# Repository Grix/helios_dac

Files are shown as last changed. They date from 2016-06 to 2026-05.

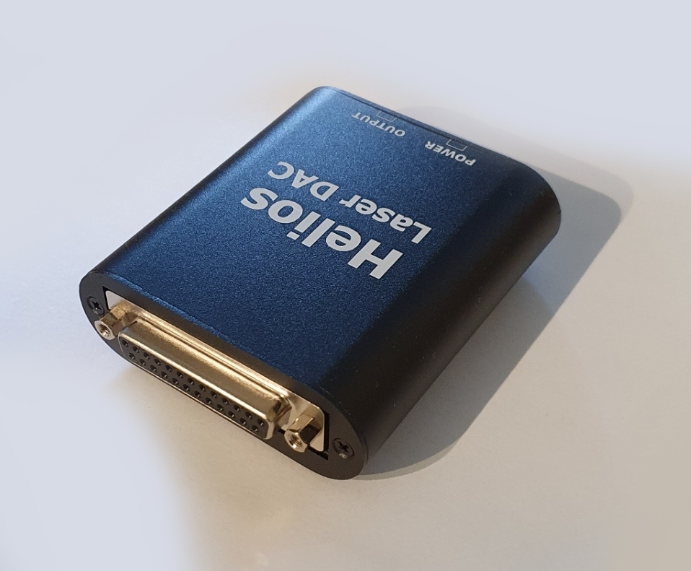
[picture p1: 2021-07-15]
media/helios_ildaside.jpg

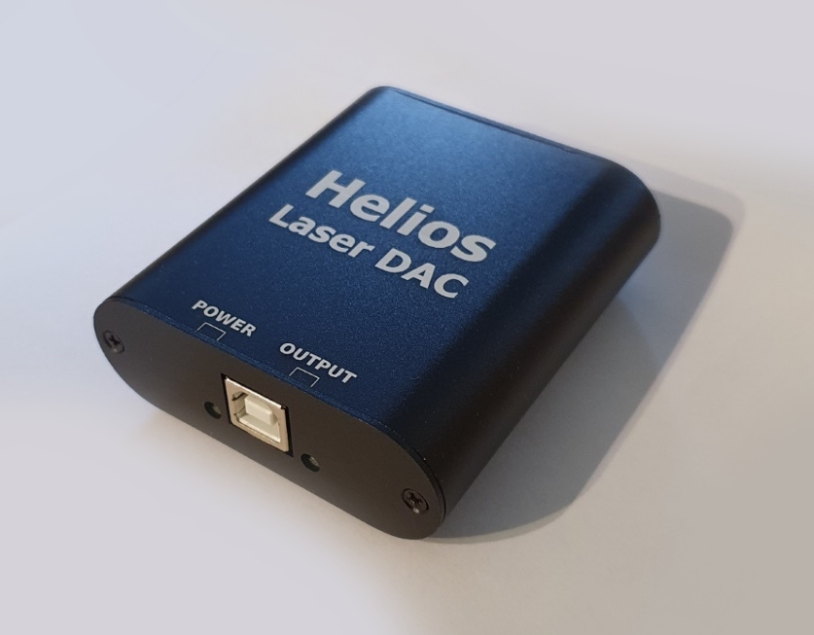
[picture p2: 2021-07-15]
media/helios_usbside.jpg

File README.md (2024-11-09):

# Helios Laser DAC
Digital to Analog Converter for laser projectors.

* https://bitlasers.com/helios-laser-dac/

Open source, low cost USB DAC for the ISP-DB25 (ILDA) laser protocol. Allows you to control an ILDA laser projector via computer over USB. Supports lots of third party software (see link above). This repository consists of:
* SDK for supporting the Helios USB and IDN DACs in your software (with examples in C++, Python and C#/.NET)
* Hardware (PCB schematic in KiCAD)
* Firmware (Atmel Studio project)
* Extras (firmware update tool, media etc.)

## Developer guide

#### Third party software integration

Navigate to the folder "sdk" to find the relevant code for interfacing with the Helios DAC in your software, and a readme with more detailed usage instructions. 

NEW: The C++ sdk has been updated to include IDN network support. This means that if you implement/update the Helios library in your application, it will also seamlessly enable support for any other network DAC using the IDN protocol, including the Helios OpenIDN adapter, StageMate ISP, and upcoming Helios products.
**Other libraries than the C++ one has not yet been updated with IDN support.**

The reference SDK is written in C++, in the subfolder "cpp". But libraries with exported functions that you can call from many languages such as python or C# are available, documented in HeliosDacAPI.h. You can also find examples of usage in the examples folder.

The C++ code depends on libusb. You can use the included libusb binary libraries for Win32, Mac or Linux, or you can build your own. You can find the libusb source on libusb.info, or binaries on https://sourceforge.net/projects/libusb/files/libusb-1.0/

If you wish to use the shared library, there are ready-made builds for Win32 (.dll) and 64-bit linux (.so) in the sdk folder. NB: Only the Windows binary is guaranteed to be up to date. For Mac and Linux it is recommended to build your own or use the C++ classes.

New: There is a native .NET library with example code in sdk/dotnet. HOWEVER, the C# library is not yet updated with IDN (network) support, so it is not recommended for general use yet.

If you are adding support for the Helios in your program, let me know and I can link it on the Helios' website.

Steps to compiling shared library (.so) for Linux based systems yourself is below. For macOS, try replacing ".so" with ".dylib". For Windows, there is a Visual Studio project in the source directory.

```shell
g++ -Wall -std=c++14 -fPIC -O2 -c HeliosDacAPI.cpp
g++ -Wall -std=c++14 -fPIC -O2 -c HeliosDac.cpp
g++ -shared -o libHeliosDacAPI.so HeliosDacAPI.o HeliosDac.o libusb-1.0.so
```
To use the device on Linux you either need root privileges or need to set up udev rules (see https://bitlasers.com/helios-laser-dac/). On Windows and Mac it should be plug and play.

A more detailed guide for compiling for Raspberry Pi (Linux ARM) is also available in the docs folder.

#### Hardware and firmware modification

The PCB is drawn in Kicad. The firmware is written and built with Atmel Studio for the ATSAM4S2B microcontroller.
**NB: The license for the hardware and firmware, unlike the software, does not permit the sale of manufactured units.**
New firmware can be uploaded to the device over USB. To do this, you must reset the "GPNVM1" bit in the flash memory, which will make the microcontroller boot to the SAM-BA bootloader. You can do this by sending a special interrupt packet to the DAC. You can then access the flash using Atmel's SAM-BA software or BOSSA. There is an automatic tool for firmware updating:

* Download the firmware updating tool (only for Windows as of now, Mac/Linux partially done): utility/FirmwareUpdater/cli/firmwareupdater_script.zip
* Unzip, plug in the DAC and run the file "flash.bat".
* Follow the instructions on the screen (you may need to unplug and replug the device a couple of times as instructed).

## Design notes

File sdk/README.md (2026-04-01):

There are currently official libraries for C++ and C#, see the respective subfolders. 
There also exists Rust and Javascript libraries from third parties, but they are not covered here.

**NEW**: As of October 2024, the C++ SDK has been updated to include IDN (network) support. This means that if you implement/update the Helios library in your application, it will also seamlessly enable support for any other network DAC using the IDN protocol, including the Helios OpenIDN adapter, StageMate ISP, and upcoming Helios products. This also enables more capabilities such as higher resolution and more data channels. This is reflected by the choice of multiple WriteFrame\*() functions, such as WriteFrameHighResolution() and WriteFrameExtended(). 
**Since only the C++ library supports this as of now, it is recommended to use that. Other languages can link to the C++ share libraries dynamically.**
The original WriteFrame() with 12-bit XY resolution and 8-bit RGBI channels have been preserved for backwards compatibility and a light-weight alternative, but for new or updated applications, it is recommended to choose at least WriteFrameHighResolution() instead. It gives you the most common channels, XY+RGB, with 16-bit resolution each. It is safe to call this function even if the DAC in use does not support these resolutions, the library will automatically convert the data.

Common to all languages:

BASIC USAGE, common to all languages:
1.	Call OpenDevices() to scan and open devices, returns number of available devices.
2.	To send a new frame, first call GetStatus(). The status should be polled until it returns ready. It can fail to return ready on the first try.
3.  When GetStatus() has returned ready (1), then you can call one of the WriteFrame\*() functions with image data, to output a frame.
4.  Repeat steps 2-3 continuously while you have data to output. If you output to multiple DACs at once, each should have their own thread.
5.  To stop output, use Stop(). To restart output you must send a new frame as described above.
6.	When the DAC(s) are no longer needed, free the connections using CloseDevices().

The DAC is double-buffered. When it receives its first frame, it starts outputting it. When a second frame is sent to 
the DAC while the first frame is being played, the second frame is stored in the DACs memory until the first frame 
finishes playback, at which point the second, buffered frame will start playing. If the DAC finished playback of a frame
without having received and buffered a second frame, it will by default loop the first frame until a new frame is
received (but the flag HELIOS_FLAG_SINGLE_MODE will make it stop playback instead).
The GetStatus() function actually checks whether or not the buffer on the DAC is empty or full. If it is full, the DAC
cannot receive a new frame until the currently playing frame finishes, freeing up the buffer.

----

Did you know that the Helios DAC SDK won first place in the 2025 [ILDA Fenning Award for Technical Achievement (IDN Standards category)](https://www.ilda.com/awards.htm)?

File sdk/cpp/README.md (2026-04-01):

SDK for Helios Laser DAC class  
By Gitle Mikkelsen  
gitlem@gmail.com  

Dependencies:  
Libusb 1.0 (GNU Lesser General Public License, see libusb.h)

Standard: C++14

git repo: https://github.com/Grix/helios_dac.git

BASIC USAGE:
1.	Call OpenDevices() to scan and open devices, returns number of available devices.
2.	To send a new frame, first call GetStatus(). The status should be polled until it returns ready. It can fail to return ready on the first try.
3.  When GetStatus() has returned ready (1), then you can call one of the WriteFrame\*() functions with image data, to output a frame.
4.  Repeat steps 2-3 continuously while you have data to output. If you output to multiple DACs at once, each should have their own thread.
5.  To stop output, use Stop(). To restart output you must send a new frame as described above.
6.	When the DAC(s) are no longer needed, free the connections using CloseDevices().

The DAC is double-buffered. When it receives its first frame, it starts outputting it. When a second frame is sent to 
the DAC while the first frame is being played, the second frame is stored in the DACs memory until the first frame 
finishes playback, at which point the second, buffered frame will start playing. If the DAC finished playback of a frame
without having received and buffered a second frame, it will by default loop the first frame until a new frame is
received (but the flag HELIOS_FLAG_SINGLE_MODE will make it stop playback instead).
The GetStatus() function actually checks whether or not the buffer on the DAC is empty or full. If it is full, the DAC
cannot receive a new frame until the currently playing frame finishes, freeing up the buffer.

**NEW**: As of October 2024, the C++ SDK has been updated to include IDN (network) support. This means that if you implement/update the Helios library in your application, it will also seamlessly enable support for any other network DAC using the IDN protocol, including the Helios OpenIDN adapter, StageMate ISP, and upcoming Helios products. This also enables more capabilities such as higher resolution and more data channels. This is reflected by the choice of multiple WriteFrame\*() functions, such as WriteFrameHighResolution() and WriteFrameExtended(). 
The original WriteFrame() with 12-bit XY resolution and 8-bit RGBI channels have been preserved for backwards compatibility and a light-weight alternative, but for new or updated applications, it is recommended to choose at least WriteFrameHighResolution() instead. It gives you the most common channels, XY+RGB, with 16-bit resolution each. It is safe to call this function even if the DAC in use does not support these resolutions, the library will automatically convert the data.

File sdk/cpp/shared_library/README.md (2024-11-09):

This is the shared library extension of the Helios DAC SDK, used to produce a library file for dynamic linking, like .dll, .so or .dylib. It has compatibility functions with the EzAudDac functions. 
If dynamic linking is not neccessary, you can simply use the files in the parent folder (HeliosDAC.cpp, HeliosDAC.h and the source files in the idn folder) directly in your source code, with no additional files or build steps needed.

NB: These libraries depend on libusb. In addition to HeliosLaserDAC.dll/dylib/so you also need libusb-1.0.dll/dylib/so in the same folder, or installed on the computer some other way. You can find these files in the ../libusb_bin folder.

BASIC USAGE:
1.	Call OpenDevices()  to open devices, returns number of available devices.
2.	To send a new frame, first call GetStatus(). If the function returns ready, (1), then you can call WriteFrame\*().
	The status should be polled until it returns ready. It can and sometimes will fail to return ready on the first try.
3.  To stop output, use Stop(). To restart output you must send a new frame as described above.
4.	When the DAC is no longer needed, free it using CloseDevices().

When the DAC receives its first frame, it starts outputting it. When a second frame is sent to
the DAC while the first frame is being played, the second frame is stored in the DACs memory until the first frame
finishes playback, at which point the second, buffered frame will start playing. If the DAC finished playback of a frame
without having received and buffered a second frame, it will by default loop the first frame until a new frame is
received (but the flag HELIOS_FLAG_SINGLE_MODE will make it stop playback instead).
The GetStatus() function actually checks whether or not the buffer on the DAC is empty or full. If it is full, the DAC
cannot receive a new frame until the currently playing frame finishes, freeing up the buffer.

**NEW**: As of October 2024, the C++ SDK has been updated to include IDN (network) support. This means that if you implement/update the Helios library in your application, it will also seamlessly enable support for any other network DAC using the IDN protocol, including the Helios OpenIDN adapter, StageMate ISP, and upcoming Helios products. This also enables more capabilities such as higher resolution and more data channels. This is reflected by the choice of multiple WriteFrame\*() functions, such as WriteFrameHighResolution() and WriteFrameExtended(). 
The original WriteFrame() with 12-bit XY resolution and 8-bit RGBI channels have been preserved for backwards compatibility and a light-weight alternative, but for new or updated applications, it is recommended to choose at least WriteFrameHighResolution() instead. It gives you the most common channels, XY+RGB, with 16-bit resolution each. It is safe to call this function even if the DAC in use does not support these resolutions, the library will automatically convert the data.

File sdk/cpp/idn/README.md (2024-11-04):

IDN (ILDA Digital Network) is the protocol used by the network connection of the HeliosPRO. You shouldn't have to deal directly with any of the files in this folder, but in case you need documentation on IDN, see http://ilda-digital.com/

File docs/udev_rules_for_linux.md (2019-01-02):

# How to access the Helios DAC without requiring root privileges

Linux systems normally require running with `sudo` to access USB devices. `udev` rules can be used to allow access without requiring root privileges.

(This solution has been tested on a Raspberry Pi running Raspbian Stretch 2018-06-27. Other flavors of Linux may work differently.)

1. Create a file *heliosdac.rules* in /etc/udev with the contents:

		ACTION=="add", SUBSYSTEM=="usb", ATTRS{idVendor}=="1209", ATTRS{idProduct}=="e500", MODE="0660", GROUP="plugdev"

1. Create a link in /etc/udev/rules.d to *heliosdac.rules*:

		cd /etc/udev/rules.d
		sudo ln -s /etc/udev/heliosdac.rules 011_heliosdac.rules
	
1. Make sure the user account communicating with the DAC is in the *plugdev* group. On a Raspberry Pi, the "pi" user is in the *plugdev* group by default.

1. Issue the command `sudo udevadm control --reload` (or restart the computer).

## Confirming a device's vendor and product IDs

1. Disconnect the device.
1. In a terminal window, run the command `dmesg --follow`.
1. Connect the device.

Example output:

	[ 8239.754638] usb 1-1.4: new full-speed USB device number 16 using dwc_otg
	[ 8244.968718] usb 1-1.4: New USB device found, idVendor=1209, idProduct=e500
	[ 8244.968731] usb 1-1.4: New USB device strings: Mfr=1, Product=2, SerialNumber=0
	[ 8244.968739] usb 1-1.4: Product: Helios Laser DAC
	[ 8244.968748] usb 1-1.4: Manufacturer: Gitle Mikkelsen
	
These are the idVendor and idProduct values used in *heliosdac.rules*.

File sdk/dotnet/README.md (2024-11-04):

NB: The .NET library for the Helios DAC is currently in beta. It should in theory work on all platforms supporting Libusb, but it has only been tested on Win64 on .NET 6.0.
ALSO: The .NET library has not been updated with support for IDN (network DACs), only Helios USB.

**If you experience problems or want to use IDN too, consider using the C++ library and call the dll from C# using interop instead.**

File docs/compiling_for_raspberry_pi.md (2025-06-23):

Steps to compiling shared library (.so) for Linux RPi based systems
yourself:

Before : install libusb library
```shell
sudo apt-get install libusb-1.0-0-dev
```

Make sure you are in the sdk/cpp/shared_library folder in the terminal.

Compile
```shell
g++ -Wall -std=c++14 -fPIC -O2 -c HeliosDacAPI.cpp
g++ -Wall -std=c++14 -fPIC -O2 -c ../HeliosDac.cpp
g++ -Wall -std=c++14 -fPIC -O2 -c ../idn/idn.cpp
g++ -Wall -std=c++14 -fPIC -O2 -c ../idn/idnServerList.cpp
g++ -Wall -std=c++14 -fPIC -O2 -c ../idn/plt-posix.cpp
g++ -shared -o libHeliosDacAPI.so -lusb-1.0 HeliosDacAPI.o HeliosDac.o plt-posix.o idn.o idnServerList.o
```

NB: To use the USB device on Linux you either need to run your app as sudo, or need to
set up udev rules (see https://github.com/Grix/helios_dac/blob/master/docs/udev_rules_for_linux.md )

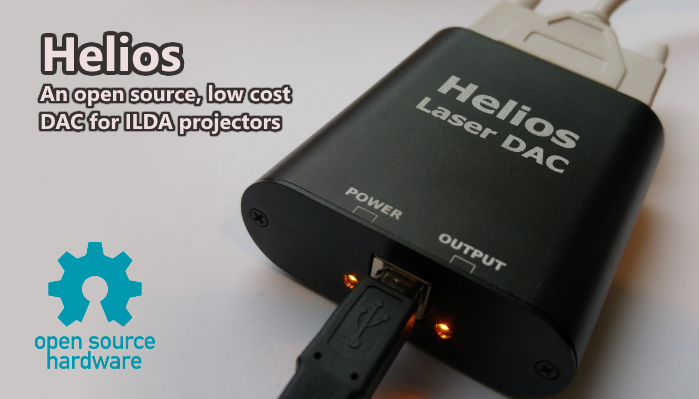
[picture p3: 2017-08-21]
media/main_withlabels.png

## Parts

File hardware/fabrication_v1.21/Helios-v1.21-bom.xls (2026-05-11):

Helios v1.21
Item | Manufacturer | Manufacturer Part Number | Designator | Qty | Description | Package / Case | SMD ,BGA,LLC(QFN),OR TH | Top/Bottom | points | Total points
1 | ST(先科) | CS1H4R7M-CRC54 | C1, C4, C6, C8, C9, C11, C23, C24, C30 | 9 | 4.7uF,50V,20%,4.00mmD*5.40mmH,2000Hrs@85℃ | 4.00mmD*5.50mmH | SMD | T | 2 | 18
2 | Yageo | CC0402KRX7R8BB104 | C2, C3, C7, C10, C13, C14, C15, C16, C17, C18, C19, C20, C21, C22, C25, C26, C27, C28 | 18 | 100nF,25V,10%,X7R,0402 | 0402 | SMD | T | 2 | 36
3 | Yageo | CC0402JRNPO9BN130 | C12, C29, C31, C32 | 4 | 13pF,50V,5%,C0G,0402 | 0402 | SMD | T | 2 | 8
4 | Yageo | RC0603JR-07150RL | R3, R4, R5, R6, R7, R8, R9, R10, R11, R12, R13 | 11 | 150R,5%,1/10W,0603 | 0603 | SMD | T | 2 | 22
5 | Yageo | RC0603FR-071K65L | R22, R33, R34, R35, R36, R45, R46, R47, R48 | 9 | 1.65K,1%,1/10W,0603 | 0603 | SMD | T | 2 | 18
6 | Yageo | RC0603FR-075K11L | R32, R16, R17, R24, R25, R30, R41, R42 | 8 | 5.11K,1%,1/10W,0603 | 0603 | SMD | T | 2 | 16
7 | Yageo | RT0603BRD0710KL | R14, R15, R18, R19, R20, R21, R23, R26, R27, R28, R29, R31, R37, R38, R39, R40, R43, R44 | 18 | 10K,0.1%,1/10W,0603 | 0603 | SMD | T | 2 | 36
8 | Jing Extension(精拓金) | 921-111A1010D10200 | P1 | 1 | Female,4Pins,90° | 16.30mmL*12.10mmW*10.90mmH | TH | T | 6 | 6
9 | TAD(泰安达) | DB-25F | P2 | 1 | Female,25Pins,90° | 53.10mmL*18.50mmW*12.55mmH | TH | T | 27 | 27
10 | UMW | IP4220CZ6 | U1 | 1 | 5.5V,SOT23-6 | SOT23-6 | SMD | T | 6 | 6
11 | Diodes Incorporated | AZ1117IH-3.3TRG1 | U2 | 1 | AZ1117IH-3.3TRG1,SOT-223 | SOT-223 | SMD | T | 4 | 4
12 | Diodes Incorporated | AN431AN-ATRG1 | U3 | 1 | AN431AN-ATRG1,SOT-23-3 | SOT-23-3 | SMD | T | 3 | 3
13 | Texas Instruments | DAC084S085CIMM/NOPB | U5 | 1 | DAC084S085CIMM/NOPB,VSSOP-10 | VSSOP-10 | SMD | T | 10 | 10
14 | STMicroelectronics | TL084CPT | U6, U8 | 2 | TL084CPT,14-TSSOP | 14-TSSOP | SMD | T | 14 | 28
15 | STMicroelectronics | LM358YDT | U7 | 1 | LM358YDT,SO-8 | SO-8 | SMD | T | 8 | 8
16 | Abracon Corporation | ABLS2-16.000MHZ-D4Y-T | Y1 | 1 | 16MHz,18pF,HC49/US | HC-49/US | SMD | T | 2 | 2
17 | Bel Fuse | 0ZCJ0110FF2E | F1 | 1 | 8V,1.1A,fuse, 1206 | 1206 | SMD | T | 2 | 2
18 | TDK Corporation | MPZ1608B471ATA00 | L1, L2, L3 | 3 | 470R,1A,0603 | 0603 | SMD | T | 2 | 6
19 | Kingbright | APA1606SYCK | D1, D2 | 2 | Yellow,2V,150mcd,2-SMD | 2-SMD | SMD | T | 2 | 4
20 | Yageo | RC0603JR-0727RL | R1, R2 | 2 | 27R,5%,1/10W,0603 | 0603 | SMD | T | 2 | 4
21 | Murata Power | CRV1D0512SC | U4 | 1 | 4.5-5.5Vin,±12Vout,15.20mmL*8.50mmW*7.30mmH | 7-SIP, 5 leads | TH | T | 5 | 5
22 | Microchip Technology | ATSAM4S2BB-ANR | U9 | 1 | ATSAM4S2BB-ANR,64-LQFP | 64-LQFP | SMD | T | 64 | 64

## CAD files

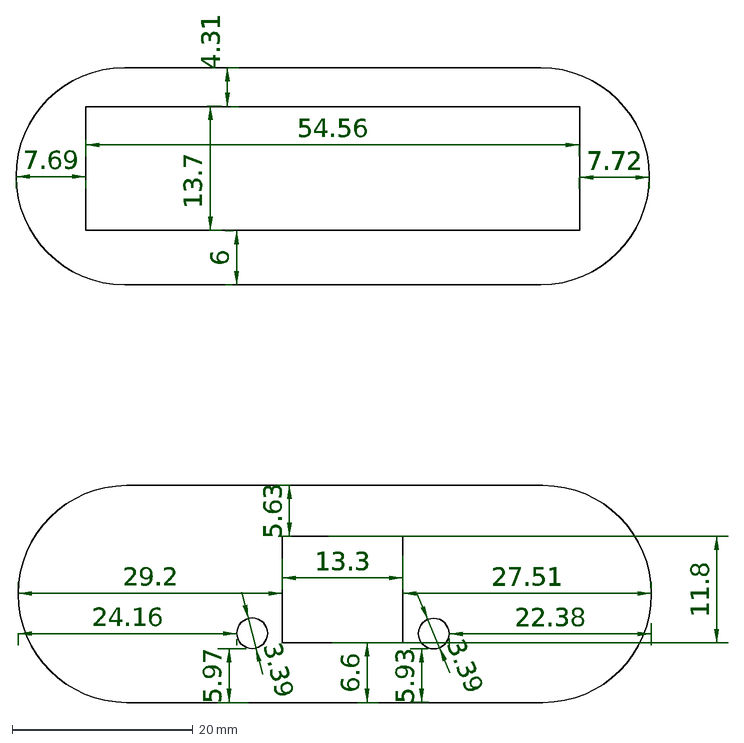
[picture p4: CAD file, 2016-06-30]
hardware/box/helios_boxcutouts.dxf
29.2
27.51
13.3
6.6
5.63
3.39
24.16
22.38
5.97
5.93
11.8
7.69
7.72
54.56
6
4.31
13.7

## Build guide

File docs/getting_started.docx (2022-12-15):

## Helios

USB to ILDA (ISP-DB25) adapter.

### GETTING STARTED

Connect the device to your computer using a USB cable (included), and then to your laser show projector's ILDA-port using a male to female DB25 cable. The "Power" light should turn on. The DAC should now be detectable by compatible software. When the DAC is outputting signals to the laser projector, the "Output" light will be lit.

When using lasers, it is important to practice safety and familiarize yourself with local regulations.

### COMPATIBLE SOFTWARE

The Helios DAC works with many apps. Try LaserShowGen, a freemium laser show suite for both pre-programmed and live performances. It is available for Windows, Mac and Linux.

You can download LaserShowGen for free on: bitlasers.com/lasershowgen-sw

Other options include:

- Show suites: LaserShowXpress, Spaghetti Laser Show, HE-Laserscan
- Laser synthesizers: Modulaser, Maxwell, Laser Juice
- Creative coding: TouchDesigner, openFrameworks, Pure Data
- Miscellaneous: MadMapper, LaserCam, ILD Render, LFI Player

### SUPPORT

If you experience problems with the DAC, try visiting the website linked below. It contains more detailed information, and a contact form for emailing us. The Helios DAC has a warranty of two years against defects.

On the website below you can also find information about the developer tools for interfacing the DAC with your own programs. The Helios DAC is open source.

Electronics such as the Helios should be disposed of through an e-waste recycling center.

More information: bitlasers.com/helios-laser-dac

Helios DAC Getting Started - rev. 2022-04-27

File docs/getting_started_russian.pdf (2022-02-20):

## Helios

Контроллер USB - ILDA (ISP-DB25).

### НАЧАЛО РАБОТЫ

Подсоедините устройство к вашему компьютеру используя USB кабель (в комплекте), и затем к интерфейсу ILDA лазерного проектора, используя кабель папа-мама DB25. Должен загореться индикатор питания "Power". Контроллер теперь должен определяться совместимым программным обеспечением. Когда из контроллера выходит сигнал к лазерному проектору, то будет гореть индикатор "Output".

При использовании лазеров важно соблюдать меры безопасности и ознакомиться с местными правилами и законами.

### СОВМЕСТИМОЕ ПРОГРАММНОЕ ОБЕСПЕЧЕНИЕ

Helios работает со множеством программ. Попробуйте LaserShowGen, это условно-бесплатное лазерное программное обеспечение для создания шоу в заранее запрограммированных или живых выступлениях. Оно подходит для Windows, Mac and Linux.

Скачать LaserShowGen бесплатно можно по ссылке:

### bitlasers.com/lasershowgen-sw

Другое ПО включает:

- Создание шоу: | LaserShowXpress, Spaghetti Laser Show, HE-Laserscan
- Лазерные синтезаторы: | Modulaser, Maxwell
- Креативное кодирование: TouchDesigner, openFrameworks, Pure Data
- Разное: | MadMapper, LaserCam, ILD Render

### ПОДДЕРЖКА

Если у вас возникли проблемы с контроллером, попробуйте посетить веб-сайт, указанный ниже. Он содержит более подробную информацию и форму для связи с нами по электронной почте. На Helios DAC предоставляется двухлетняя гарантия от дефектов.
На приведенном ниже веб-сайте вы также можете найти информацию об инструментах разработчика для взаимодействия DAC с вашими собственными программами. Helios DAC имеет открытый исходный код.

Электронику, такую как контроллер Helios, следует утилизировать в центре по переработке электронных отходов.

### Больше информации: bitlasers.com/helios-laser-dac

Helios DAC Getting Started (Russian) - rev. 2020-11-10

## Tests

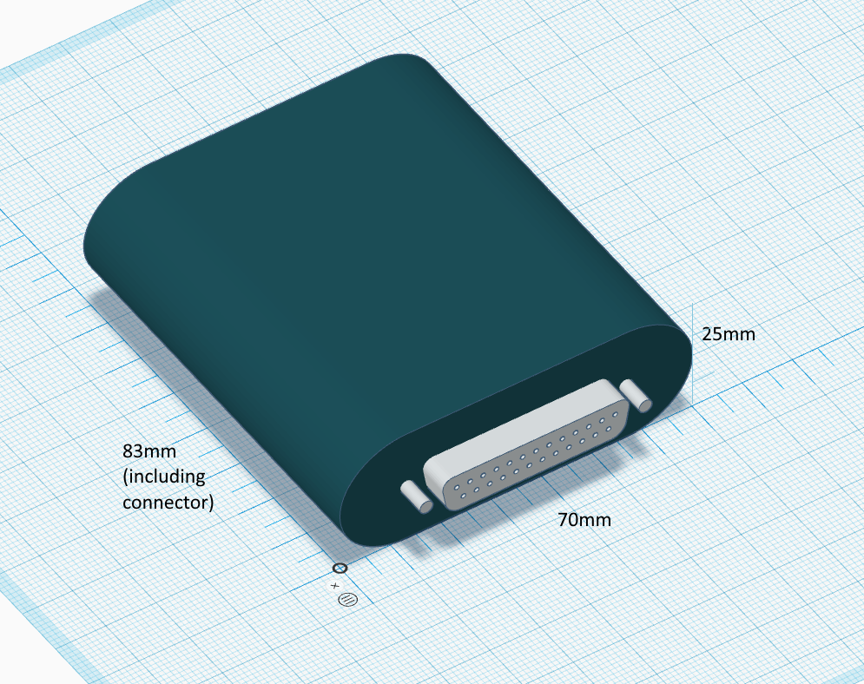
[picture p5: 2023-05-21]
media/helios_measurements.png

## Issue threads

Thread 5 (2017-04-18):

Angle optimization

xranby, 2017-04-18:
The Journal of the Society for Art and Science Vol. 7 No. 4 pp. 155 - 169
contains an easy way to improve sharpness of picture quality by
compensate for the inertia effects when the laser is taking a sharp turns.
the paper reveal that there is  an almost linear relationship between the angle of the turn and the delay to be used to mitigate the effect. - page 161
http://art-science.org/journal/v7n4/v7n4pp155/artsci-v7n4pp155.pdf

Grix, 2017-04-20:
Originally it was meant for software designers to implement their own optimization algorithms in their software before sending the data to the Helios DAC. But a feature to include this optimization in the Helios libraries directly would be useful. But it would have to be optional, by a flag in WriteFrame() for example

xranby, 2017-04-21:
masterpj55 has invented a way to render correct angles and bent lines by taking advantage of the inertia effect rather than eliminating them: https://twitter.com/masterpj55/status/853291275545653248/photo/1
this approach do not need any added delays however it would require a pass that move the x and y of the buffer data as a better way to compensate the effect.
masterpj55's method have not been described in any laser research however pragmatically masterpj55 have demonstrated that the method work.

carmangary, 2017-04-21:
xranby what you are referring to is called point pulling and is an age old method for optimizing frames.  masterpj55 did not invent it by any stretch.  The problem with it is that it only works on the scanners for which the frames have been optimized.  If you change scanner speeds to use the frames on scanners with different characteristics then the intertia will be different and the frames will look wrong.  That is the purpose of tuning scanners to an ILDA pattern.

xranby, 2017-04-21:
ILDA pattern and calibration: http://www.laserfx.com/Backstage.LaserFX.com/Systems/Scanning3.html
The correction of the under and overshoot in the corners when calibrating for the ILDA pattern is usually done by tuning delays.

The research paper from 2008 reveal that there may be a quite linear relationship between the over and undershoot when drawing corners and the paper opens up for a setting the delay dynamically based on the angle.  page 161 http://art-science.org/journal/v7n4/v7n4pp155/artsci-v7n4pp155.pdf

point pulling may be known intuitively by operators however no research is known how to automate algorithmically. i have not seen anyone describe for example how to do quick reversals without adding delays, in masterpj55's image he is adding some extra points in the opposite direction in order to do a quick scanner reversal without adding delays by thinking in more terms of how to tie a know. you can see this on the hair in his image. it would be ideal to study if arbitrarily angles can be algorithmically point pulled if you simply know the linear slope compensation depending on the angle for the scanner.

masterpj555, 2017-04-21:
It actually works on any scanner (galvo) as long as it can be properly tuned. Some manufacturers to a half assed job to tune. On top of the point pulling I use an approach to get rid of most color timing that goes a lot further in the technique.. I'm sure I wasn't the first one to figure it out but I most certainly have learned and explored it on my own to find my own techniques and analogies to describe approaches and views on how it should be done properly. When you change a scanner speed you should retune anyway.. Even non optimized graphics will look average and overscanning is a bad habit.

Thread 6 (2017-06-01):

Frames with 45 points are ignored

Grix, 2017-06-01:
Sending a frame with exactly 45 points to the DAC does not cause the laser to turn on. Problem seems to be that Atmel Software Framework's USB driver reports a wrong length of the USB transfer, causing the frame to not be parsed properly. Will investigate more.

Grix, 2017-06-11:
Fixed in sdk ver 6, pending release

Closed 2017-06-11.

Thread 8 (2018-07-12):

Linux python example issues

maltefuchs, 2018-07-12:
Hey

I recently purchased a Helios DAC and I`m having problems using the python example for linux.

I used an oszilloscope to display the output of the DAC and to eliminate any influence of other hardware. If If run LaserShowGen on OS X everything seems to work fine. The DAC is recognised and frames are shown just fine (even though somehow distorted on the oszilloscope).

However if I try to run the python example file on Ubuntu (also on a macbook) the DAC is recognized and loads the first frame but gets stuck afterwards. I tried to analyze the problem further and found that after loading the first frame HeliosLib.GetStatus(j) keeps returning 0, so it`s never ready to receive another frame.

I tried using a frame with fewer points (down to 1) but nothing changed. I also tried changing the flags of "int WriteFrame" in all sorts of combinations but wasn`t lucky either.

Has anyone observerd something similar or has any ideas how to solve the issue?

Thanks a lot for any help!

Kind regards
Malte

Grix, 2018-07-15:
Hi,
I checked and it seems the library .so file in the python example folder was outdated. I recompiled from the source and updated the file in the folder. So now it should work as-is. Try again and let me know.

maltefuchs, 2018-07-16:
Hey,

thanks a lot for the quick fix. I will test it as soon as I can and let you how it went.

Kind regards
Malte

maltefuchs, 2018-07-26:
Hi,
I just tried it again with the updated file and it works fine now. Thank you for fixing it!

Kind regards
 Malte

Grix, 2018-07-26:
Good to hear

Closed 2018-07-26.

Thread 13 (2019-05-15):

Hardware schematic update request

mrv96, 2019-05-15:
Hi, looking Helios schematics i found some mismatchings between Kicad files and both Bill Of Materials and your PCB photos. For example, from BOM and photos i can see that your DC-DC converter provides +-12V, while the schematic include a +-9V DC-DC converter. Moreover DC-DC converter isolated ground (called 0V) is connected with the main GND, making the isolation useless. I think that schematic files are not updated to the last review, can you correct this incongruences please?

Thank you very much for your amazing work!

Grix, 2019-05-16:
Hi,
I can take a look at this when I have time, it is very possible that the files are slightly outdated. But as for the DC-DC converter, it is fine with either 9V or 12V, and it does not matter that the ground is not isolated, in fact it's probably better that it's not. Its only purpose is to power the opamps.
For the record, this is the BOM that was used for the most recent actual manufacturing batch: https://docs.google.com/spreadsheets/d/1PZRa1wW3mezbmuCuooRiO7qGqE42E1tUs300BoUyFXU/edit?usp=sharing

mrv96, 2019-05-16:
Thank you very very much for the answer and for the updated BOM. I'll wait for Kikad project update. Thank you again for your work.

Grix, 2019-05-19:
It should be up to date now. Except I didn't fix some labels like the 9V because as said it doesn't really matter, I think the only reason I used a +-12V instead was that the 9V converter was out of stock.

Closed 2019-05-19.

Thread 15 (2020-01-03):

Shutter

adiastra, 2020-01-03:
I would like to use the shutter to send voltage to control a relay. Is that possible?

Grix, 2020-01-08:
The shutter is a normal on/off 5V signal, referenced to ground. So sure, it should be possible to control a relay with this. Refer to the ILDA port standard: https://www.ilda.com/resources/StandardsDocs/ILDA_ISP99_rev002.pdf

Closed 2020-01-08.

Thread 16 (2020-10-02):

Enclosure type

hires, 2020-10-02:
I'm interested in building a unit but only the PCB parts are shown in the BOM. Where is the enclosure part?

Grix, 2020-10-04:
Hi,

This is the enclosure used: https://rfbat.com/collections/box-aluminum/products/new-aluminum-box-enclousure-case-project-electronic-diy-75-70-24l-w-h-black

However, the shelf variant of that enclose does not have the required connector cutouts, we have them custom made. This is probably prohibitively expensive for a one-off build if you don't have tools to cut out connector slots yourself, but we have some spare enclosures with the cutouts and engraving left over that you can order from here if you prefer: https://bitlasers.com/shop/helios-enclosure/

Closed 2021-07-01.

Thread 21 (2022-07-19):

The XY Channel Offset

zhshaw, 2022-07-19:
Hi Grix,
I have a question about the X/Y Channel Offset.
As shown in the schematic, the voltage of Offset will be 2.5V/2/1.165=1.073V. The voltage range of X/Y should be 0.417V ~ 2.083V. The Offset voltage does not lie on the center of the X/Y range.
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

This means that the +X/+Y output range is -3.976 to 6.121V, the -X/-Y output range is -6.121 to 3.976V, and the differential voltage is between -7.952 to 12.242V. But the ILDA standard requires a +-10V differential output.
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

I wonder if my calulation is correct. Besides, is it possible to remove R22?

Thanks a lot.

Closed 2022-08-17.

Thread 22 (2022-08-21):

.NET library does not seem to work on Windows: Fails opening device

Grix, 2022-08-21:
However it does seem to possibly work on mac or linux.
Problem on Windows is that alt interface functionality is different in LibusbDotNet than normal c++ libusb. More info in this issue: https://github.com/LibUsbDotNet/LibUsbDotNet/issues/132

Closed 2023-03-31.

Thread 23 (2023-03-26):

.net library doesn't close down properly

trevorboultwood, 2023-03-26:
I am using the .net helios library which works perfectly. However, after closing the program down the thread controlling the laser does not resulting in me having to close it within windows task manager.

Grix, 2023-03-26:
There are no threads in the Helios .NET library as far as I can see... If so they are in the libusb library but that should all be freed when calling CloseDevices(). Are you sure this is a problem with the library and not a thread in your own program? If so, can you post a sample project demonstrating the issue so I can reproduce it?

trevorboultwood, 2023-03-26:
Hi Grix, I have taken the following code from your example project. If I execute heliosController.OpenDevices(); when I close/press exit my process doesn't end. (have go into task manager) if i am debugging I have to press the stop button.

I am looking at implementing your driver into my existing .net project which is sadly a .net framework  project and requires porting to .net core.

Thank you,

```
using HeliosDac;
using LibUsbDotNet.Main;
using LibUsbDotNet;
using LibUsbDotNet.WinUsb;

namespace WinFormsApp1
{
    public partial class Form1 : Form
    {
        public Form1()
        {
            InitializeComponent();
        }
        UsbRegistry usbRegistry;
        HeliosController heliosController = new HeliosController();
        private void Form1_Load(object sender, EventArgs e)
        {
            int numberOfDevices = 0;
            try
            {
                numberOfDevices = heliosController.OpenDevices();
                MessageBox.Show("Number of devices: " + numberOfDevices);
                for (int deviceId = 0; deviceId < numberOfDevices; deviceId++)
                {
                    MessageBox.Show(heliosController.GetName(deviceId));
                }
            }
            catch (Exception ex)
            {
                MessageBox.Show("Failure during detecting and opening of Helios DACs: " + ex.Message);
            }
            heliosController.CloseDevices();
        }
    }
}
```

trevorboultwood, 2023-03-26:
I should also mention, currently I do not have my Helios product connected. Will be purchasing soon just in the middle of a house move so cant confirm delivery address.

Grix, 2023-03-26:
What code does it say is running when you pause / "break all" in the debugger?

trevorboultwood, 2023-03-26:
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

Hi,

.NET ThreadPool Gate & .NET system events. Apologies, this is not my main area of expertise. Thank you for supporting me on this issue.

Grix, 2023-03-27:
I am unable to reproduce the problem. I create a new winforms app, copy in your code, run it, then close the window. Everything closes down normally, nothing stays running. Do you have anything else in your app?

trevorboultwood, 2023-03-27:
> I am unable to reproduce the problem. I create a new winforms app, copy in your code, run it, then close the window. Everything closes down normally, nothing stays running. Do you have anything else in your app?

Hi Grix, thank you for testing for me. I have have just removed all my installations of visual studio to try and get this to work and have tried a variety of project settings. Would you be able to send me over your project so i can see any differences? Apologies for the inconvenience.

I don't have anything else running my app, I created a WindowsFormApp and include the HeliosDac assembly and place the lib dlls in the windows-bin folder.

trevorboultwood, 2023-03-28:
HI Grix, thank you for sharing the project. I think however you have made a slight error. The function handler which you have copied never gets executed.

I have double click the windows form from within the designer view and it generates a new handler where I then placed the original code in.

Sadly the issue persists. I took another look last night and didn't have any luck. Thank you again.

 ```
private void Form1_Load(object sender, EventArgs e)
        {

        }

        private void Form1_Load_1(object sender, EventArgs e)
        {

            int numberOfDevices = 0;
            try
            {
                numberOfDevices = heliosController.OpenDevices();
                MessageBox.Show("Number of devices: " + numberOfDevices);
                for (int deviceId = 0; deviceId < numberOfDevices; deviceId++)
                {
                    MessageBox.Show(heliosController.GetName(deviceId));
                }
            }
            catch (Exception ex)
            {
                MessageBox.Show("Failure during detecting and opening of Helios DACs: " + ex.Message);
            }
            heliosController.CloseDevices();

        }
```

Grix, 2023-03-28:
Can you copy your entire project and send it to me then.

trevorboultwood, 2023-03-28:
[tboultwood_WFA_Helios.zip](https://github.com/Grix/helios_dac/files/11092985/tboultwood_WFA_Helios.zip)

The only notable difference between the WFA you supplied and the one I have been using on my side is you installed the NuPackage and I directly referenced the .dll supplied on your repo for LibUsbDotNet.

trevorboultwood, 2023-03-28:
Hi Grix, I have continued with some debugging and I have discovered the bug.

`UsbDevice.ForceLibUsbWinBack = true;`

This causes the application to hang and commenting it out allows the application to function correctly.

Whilst I have no hardware to test with just yet I found calling this function solves the issue. I assume this should be included in the closedevices function.

`UsbDevice.Exit();`

Thank you for providing me with assistance. I might purchase the Helios DAC to a relatives house who can forward it on to me.

Grix, 2023-03-31:
You are correct, UsbDevice.Exit() fixes the problem.

UsbDevice.ForceLibUsbWinBack needs to be true for the library to work on Windows.

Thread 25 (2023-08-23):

Disconnect ILDA ground when inactive

PatHightree, 2023-08-23:
Would it be possible to disconnect the ground of the ILDA connection until actual data is transmitted ?
I'm using a Laserworld DS1000 which has 2 inputs ILDA and ethernet.
I'd like to have keep cables connected but the ethernet input is disabled as soon as the ILDA cable is connected to the DAC.
This is by design, the manufacturer [advises](https://showcontroller.com/en/forum/hardware-and-installation/154-connect-ds1000-via-both-ethernet-and-ilda.html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) me to disconnect the ILDA cable at the DAC to use ethernet.
But he mentions that disconnecting the ILDA ground signal would also do the trick.
So I'm wondering if that could be done by the Helios DAC.

Grix, 2023-08-27:
Unfortunately this isn't possible on the official device, the ground signals in the ILDA cable are hardwired.

PatHightree, 2023-08-27:
Yeah I figured as much, thanks for confirming.

Closed 2023-08-27.

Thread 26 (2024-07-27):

DC to DC converter supply issues

KuusamoMart, 2024-07-27:
The +/- 9V DC to DC converters are becoming very difficult to procure; suggest changing to +/- 12V 1W converters instead, ensuring 4.7uF capacitors are appropriately rated. The Op-Amps can operate with +/- 15V rails, so there is no requirement to make changes to the amplifier section. As a side benefit, the ILDA specified 10V control voltage range can now be achieved, which was a limitation with the 9V converters.

Grix, 2024-07-28:
12V can be used interchangeably.
However there was never any problem with ILDA spec. I'm guessing the 10V voltage you are referring to is the XY signals, however the *differential* signal is 10V, meaning that each line is 5V and -5V with respect to ground, so the +/-9V converter has no problem with it.

TrevorPage, 2024-07-28:
The BOM already states a +/-12V part, and did so at least as far back as 2022 when I ordered components.

For added information, here in the UK I successfully used Farnell part numbers [3652675](https://uk.farnell.com/multicomp-pro/mpe0512xt-1w/dc-dc-converter-2-o-p-1w/dp/3652675) and https://uk.farnell.com/multicomp-pro/mpa0512xt-1w/dc-dc-converter-2-o-p-1w/dp/3652640.

KuusamoMart, 2024-07-29:
Ah, the BOM in the repository has been updated, but  because I generated the Gerbers in KiCAD from scratch, the BOM only showed the 9V converter. The change needs to be flowed back to the KiCAD design.

TrevorPage, 2024-08-04:
Ah, gotcha! Nice to meet someone else building this BTW! (Slight cheeky hijack: If it's any interest, I'm personally using my fork of https://github.com/TrevorPage/laser-dac within my own software for this interface.)

mael214, 2025-05-19:
Hi guys !
All of your parts are not longer available.
Do i have to rework the PCB or maybe you have other parts that could fit ?
Kr

TrevorPage, 2025-05-19:
@mael214 are you referring to the DC/DC converter? You have replied in an issue concerning specifically the DC/DC converter, but you said "all of your parts", so it is unclear.

A DC/DC converter I have successfully used, which is still available, is:

https://uk.farnell.com/multicomp-pro/mpe0512xt-1w/dc-dc-converter-2-o-p-1w/dp/3652675?CMP=i-bf9f-00001000

mael214, 2025-05-19:
@TrevorPage Yeah sorry :/
This one https://uk.farnell.com/multicomp-pro/mpa0512xt-1w/dc-dc-converter-2-o-p-1w/dp/3652640 you mentionned earlier in the thread is discontinued.

I will check on similar one then !

Thanks a lot !

TrevorPage, 2025-05-19:
@mael214 if it's any help, Mouser also stock the Traco part: https://www.mouser.co.uk/ProductDetail/TRACO-Power/TES-1-0522?qs=ckJk83FOD0Xz2aGJiyeZmw%3D%3D

Grix, 2025-05-19:
Another alternative for the PSU is Recom R1DX-0512-R.
All the parts on the board have alternatives that are easy to procure, I just ordered a new official batch myself.

and-pad, 2025-07-22:
Hi I recently made a lot of 5 cards and I can't make it work, the only one different that I made is change the ISA0512-TR (obsolete) for one IAS0105D12, which is its direct replacement, I was compared the two datasheets, in this moment I haven't an osciloscope is in way, but any of yours has passed for this problem or know where I can search.

Thanks a lot

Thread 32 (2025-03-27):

LIST BOM

RoDanny2021, 2025-03-27:
Hello,
Very interesting project. I would like to know if you can give me a bill of materials (BOM), I would try to make the interface in diy mode. I found your pcb publicly for sale on PCBWay, but although there are grb files, there is no BOM. Thank you.

TrevorPage, 2025-03-27:
The BOM, together with Gerber files and other fabrication data, is all contained in the /hardware directory of this repository.

RoDanny2021, 2025-03-27:
Ok ,

Thank you so much...

Tell me in BOM 2 component is red ....why?

After make controller, can help to guide me to put firmware?

Best,

Danny

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

RoDanny2021, 2025-03-27:
Sorry and new ask...

Bom from git is 2018.3.17 but all files is from date 2016-08-13 10:38.46

It’s change anything.

On pcbway is last schematic pcb?

If can buy components and pcb from pcbway ...in final can obtain an working interface ?

Sory for my poor English

Best,

Danny

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

Closed 2025-03-27.

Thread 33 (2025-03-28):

Using Helio for laser machine selling

shihweichieh2023, 2025-03-28:
Hi there,

I am developing a project for a [customized and modular laser galvo system](https://shihweichieh.com/Wei-Wei-Laser). I am a Max/MSP user on Mac, and I started with an expansive MOTU sound card before switching to a DIY card (Teensy 4.1 + CS42448). Unfortunately, the DIY card only works on PC.

I understand that Helio provides a USB interface and supports TDM, and that no drivers are needed on Mac—though I assume the software might work a bit differently. I checked the Pure Data (PD) patch, and it seems that Helio does not function in the same way as Teensy, which can be selected as an audio interface with multiple audio output channels. Could anyone clarify how Helio works in this context? How can I use Helio as a sound card on Mac?

Thank you for your feedback!

Grix, 2025-03-29:
It doesn't work as a native sound card, it needs a custom USB Vendor class driver. The protocol can be understood from the source files, either the SDK or the firmware.

shihweichieh2023, 2025-04-01:
yea nice, thanks for the respond! I now go to another solution with teensy and CM6062 over USB host, however I use pure audio synthesis to drive my galvo not ILDA.

Closed 2025-03-28.

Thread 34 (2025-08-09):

Multiple IDN devices report the same name

aWZHY0yQH81uOYvH, 2025-08-09:
After calling `OpenDevices()`, both of my OpenIDN devices (which have different hostnames and different Helios device names) report the same name when queried using `GetName()`. Only the second device is getting sent a `SERVICEMAP_REQEST` packet and its hostname and service name are reported for both devices. Unplugging the second device causes the name of the first device to be reported correctly.

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

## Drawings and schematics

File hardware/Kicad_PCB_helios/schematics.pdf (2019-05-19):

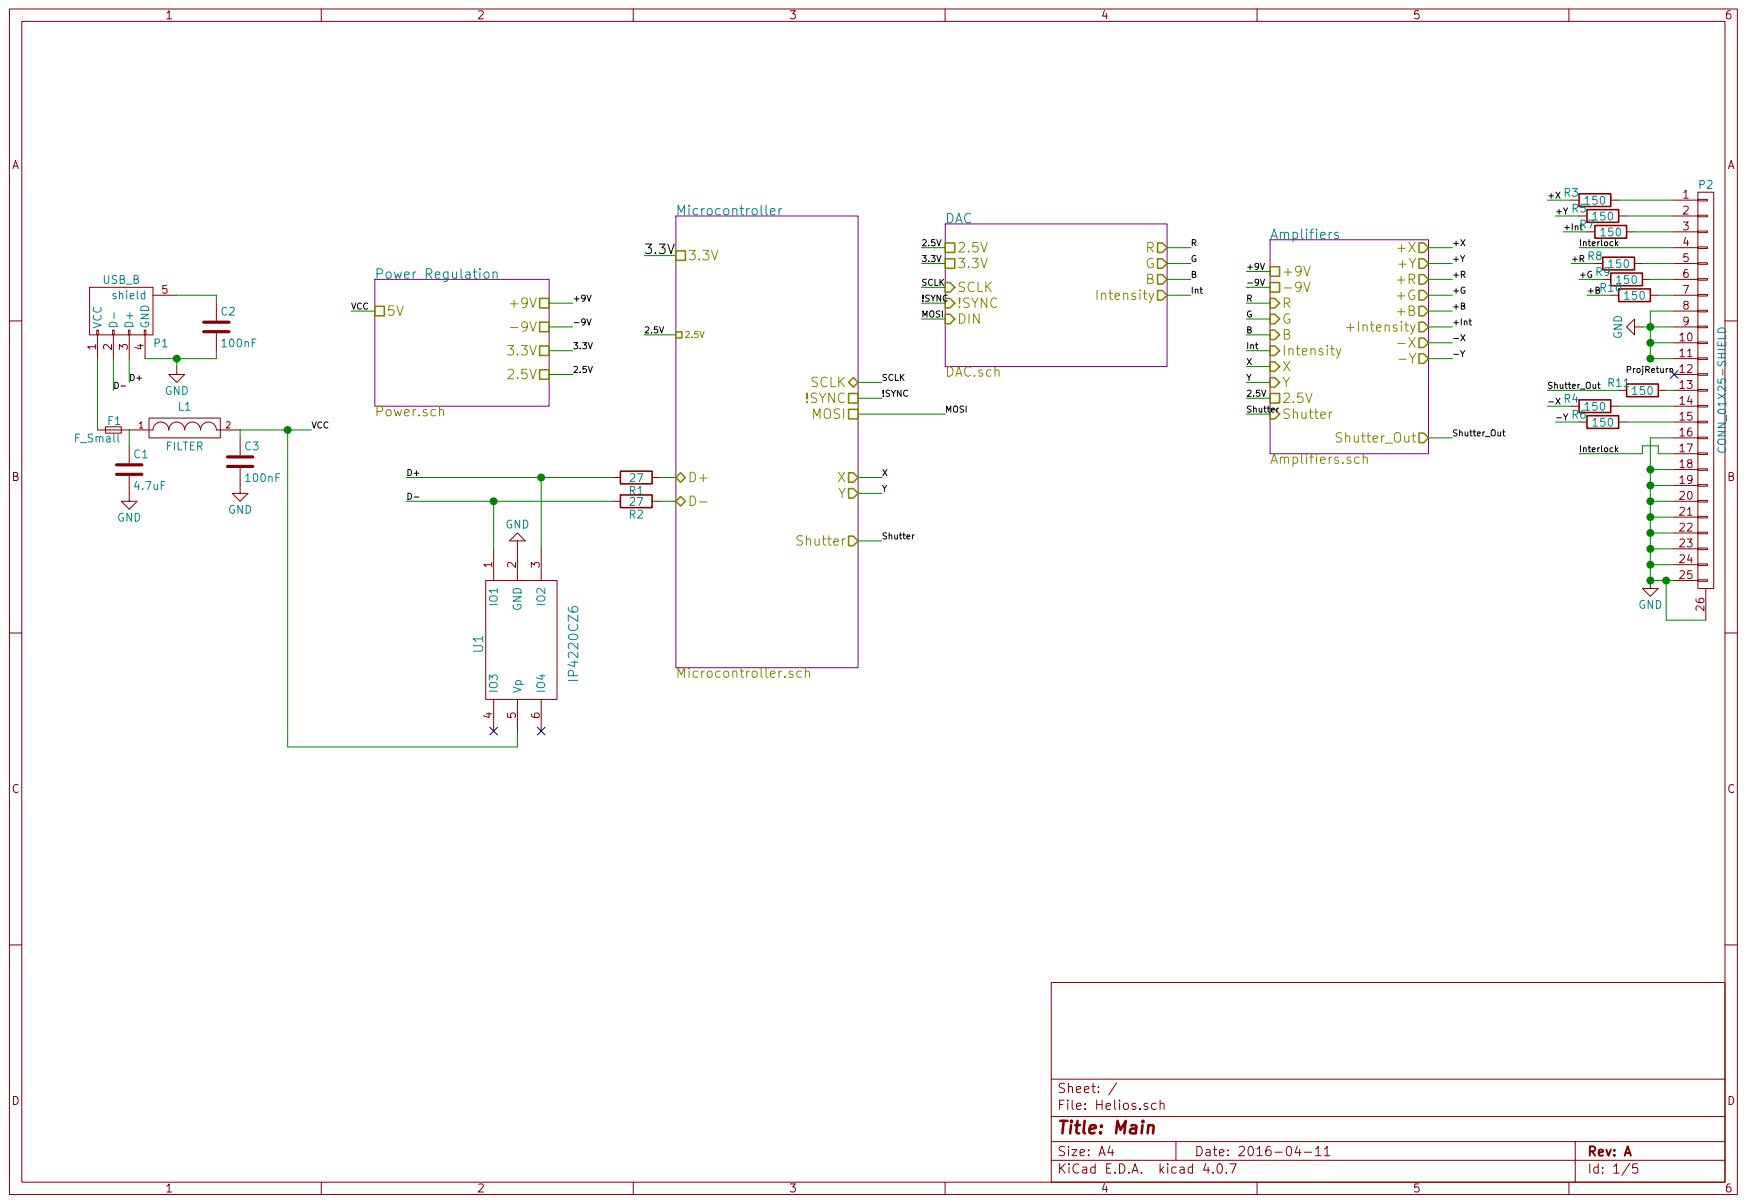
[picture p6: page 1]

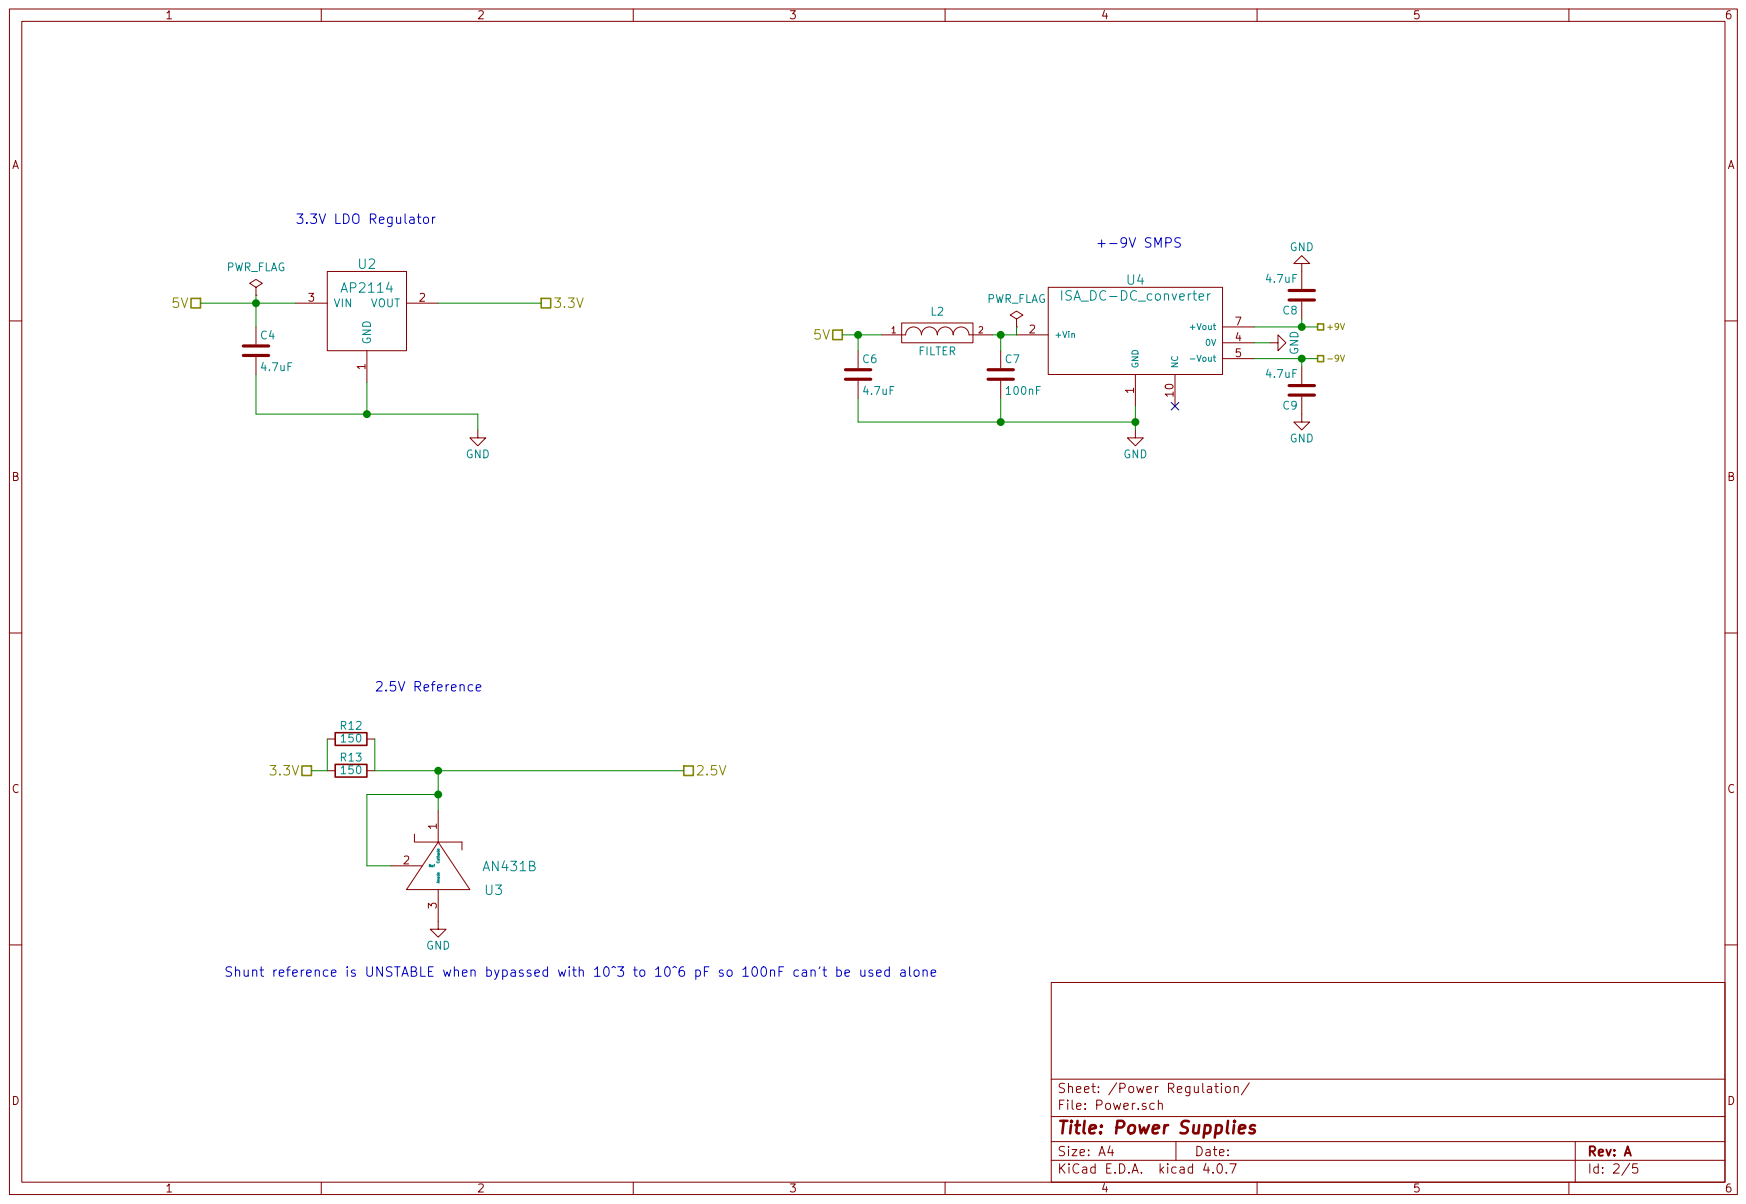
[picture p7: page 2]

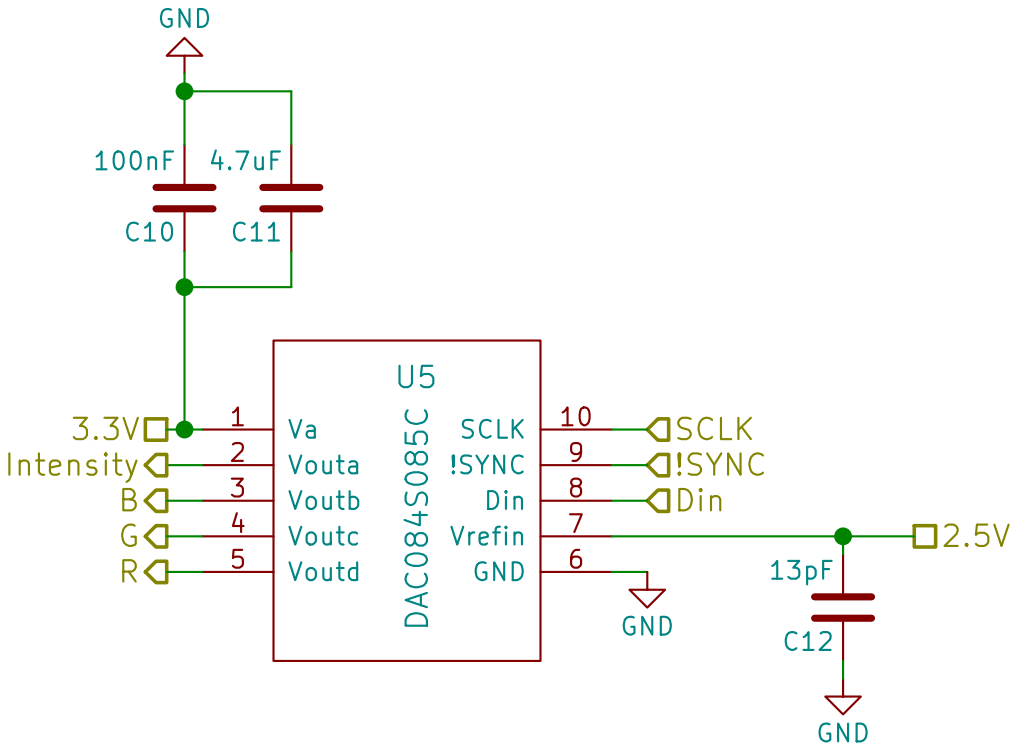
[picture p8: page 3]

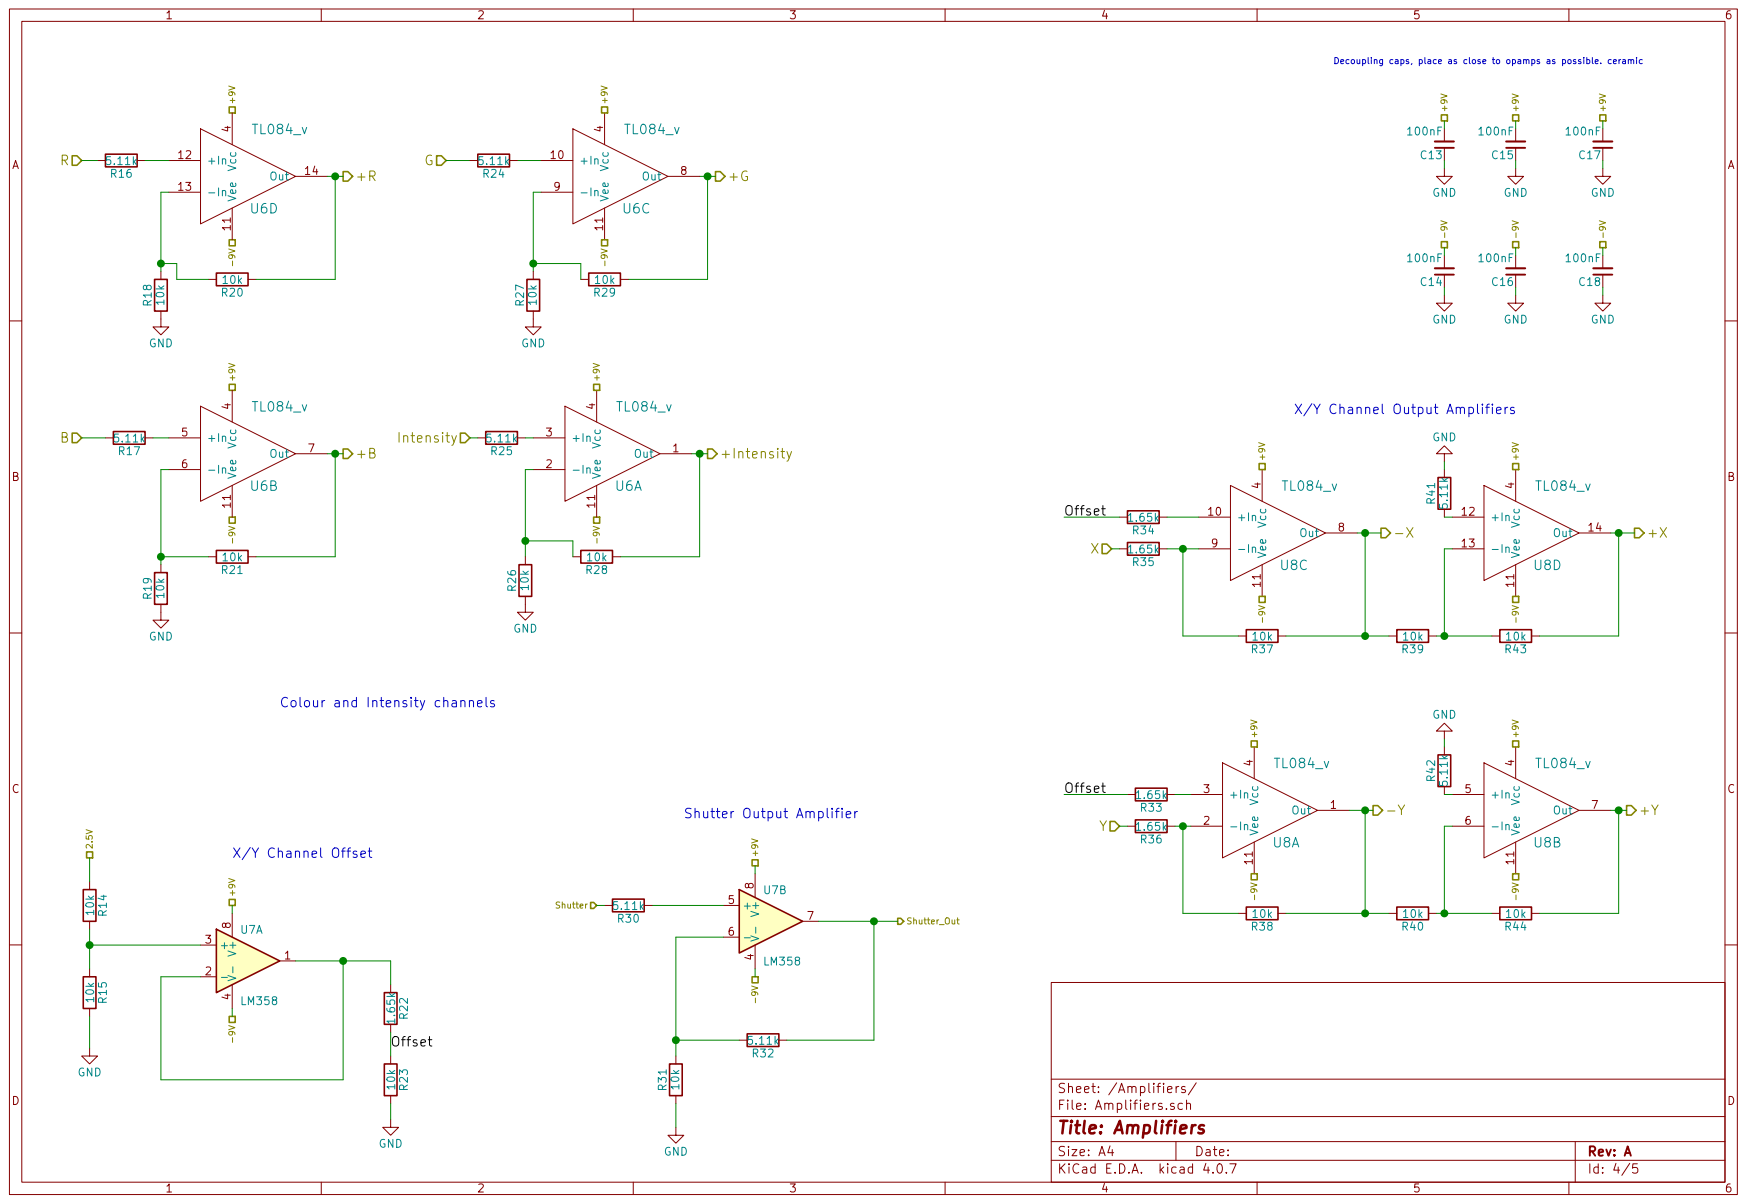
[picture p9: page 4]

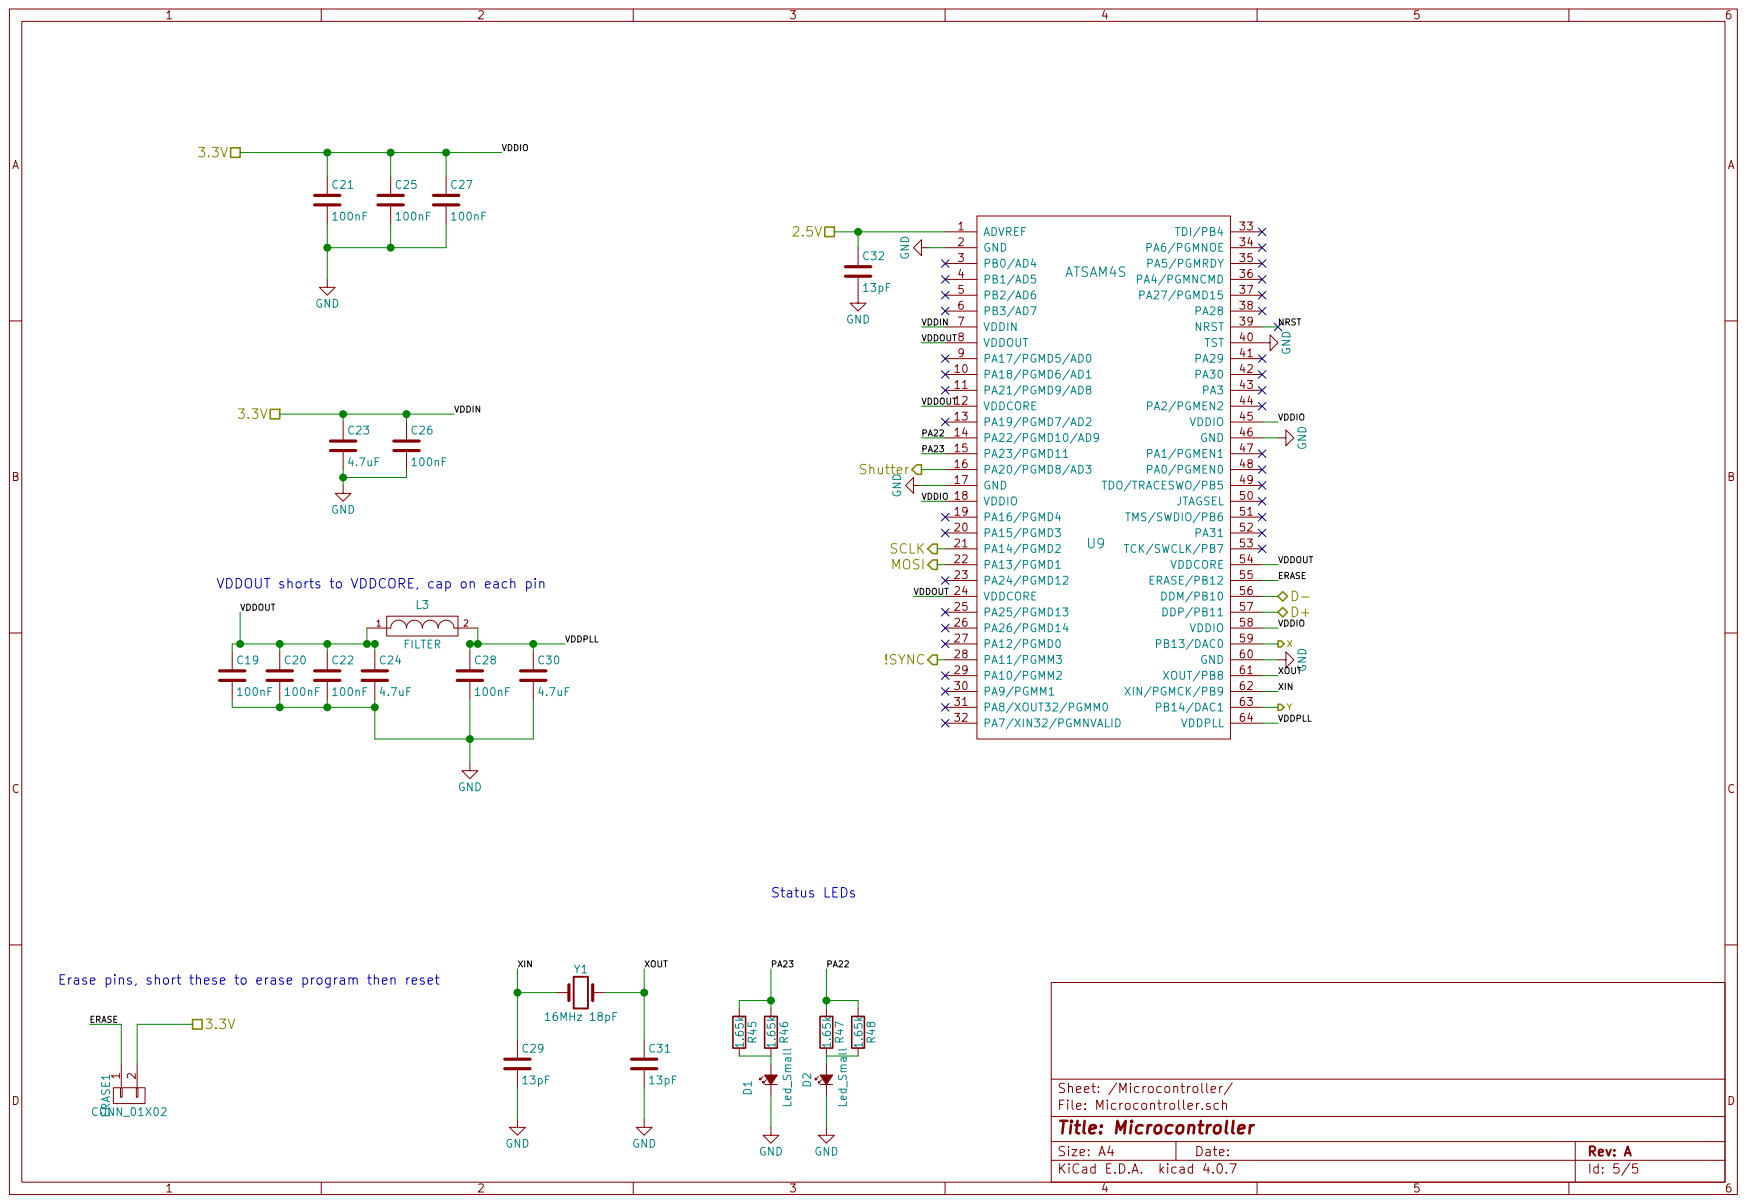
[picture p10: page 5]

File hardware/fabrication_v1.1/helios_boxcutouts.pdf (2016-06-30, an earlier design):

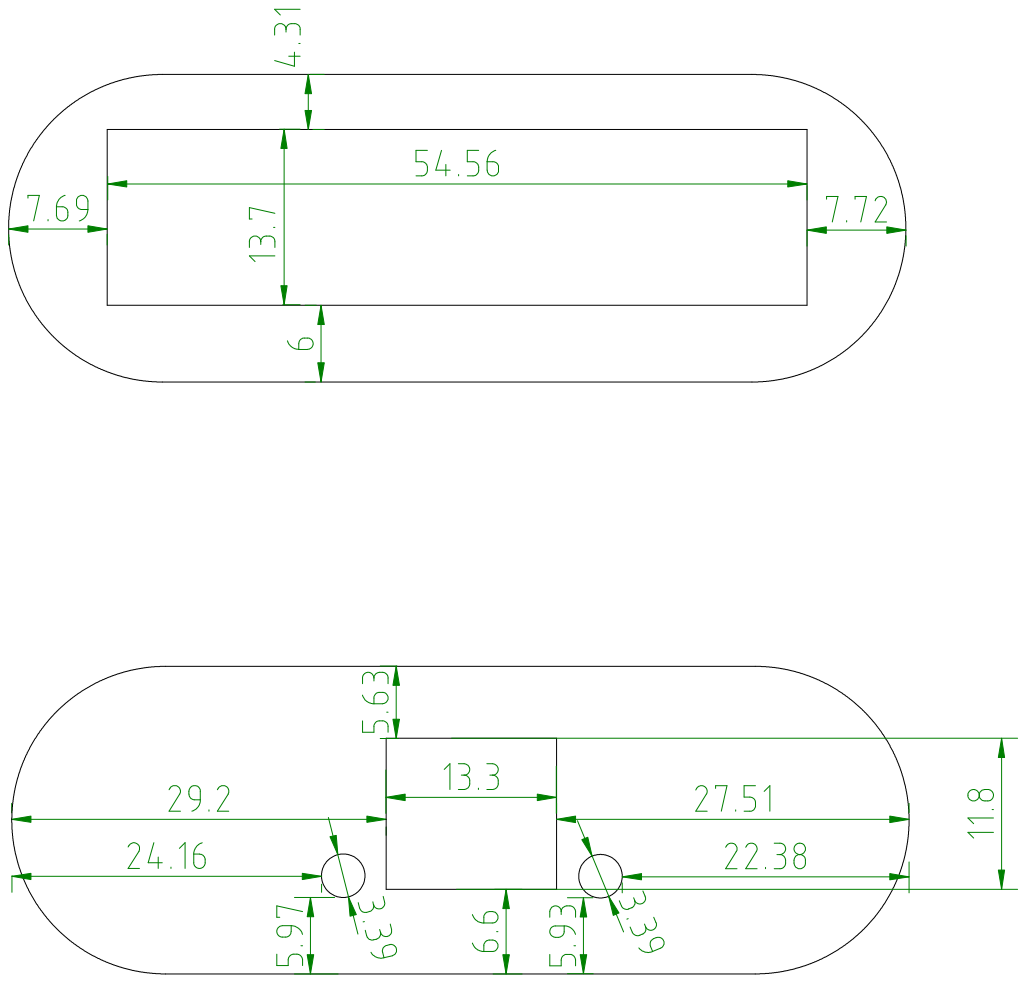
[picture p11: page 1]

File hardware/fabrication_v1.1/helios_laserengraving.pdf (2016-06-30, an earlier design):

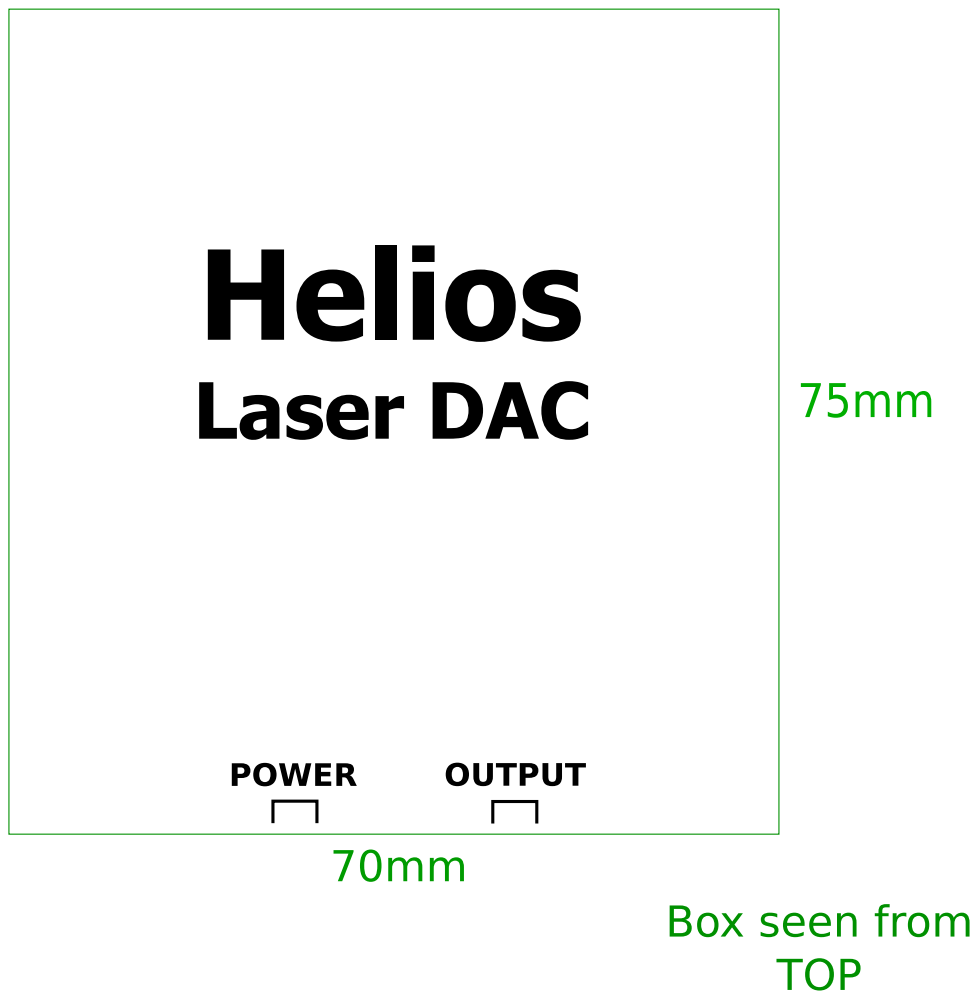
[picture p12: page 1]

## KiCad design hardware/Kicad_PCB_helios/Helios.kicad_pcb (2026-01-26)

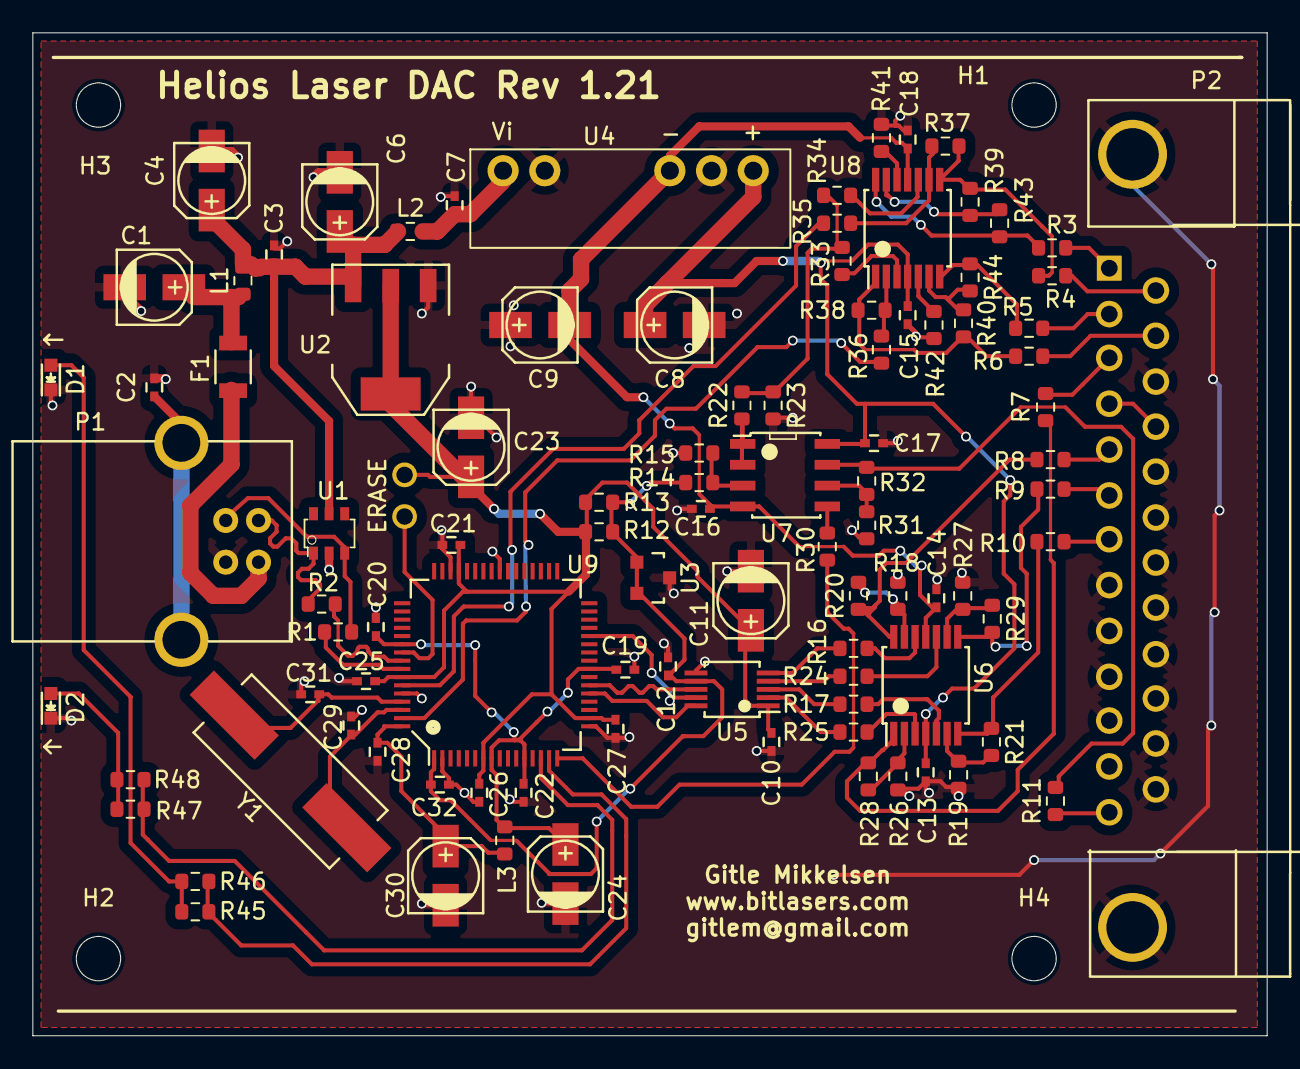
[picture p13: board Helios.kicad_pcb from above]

Board: 2 copper layers, 75.2 x 61.1 mm, 102 parts (0 on the bottom side), 50 nets.

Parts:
C1, C4, C6, C8, C9, C11, C23, C24, C30: 4.7uF; c_elec_4x5.3
C2, C3, C7, C10, C13, C14, C15, C16, C17, C18, C19, C20, C21, C22, C25, C26, C27, C28: 100nF; C_0402
C12, C29, C31, C32: 13pF; C_0402
D1, D2: Led_Small; LED_0603
ERASE: CONN_01X02; PINHEAD1-2
F1: F_Small; R_1206
H1, H2, H3, H4: MountingHole; MountingHole_2.7mm_M2.5
L1, L2, L3: FILTER; R_0603_1608Metric
P1: USB_B
P2: CONN_01X25-SHIELD; DB25
R1, R2: 27; R_0603_1608Metric
R3, R4, R5, R6, R7, R8, R9, R10, R11, R12, R13: 150; R_0603_1608Metric
R14, R15, R18, R19, R20, R21, R23, R26, R27, R28, R29, R31, R37, R38, R39, R40, R43, R44: 10k; R_0603_1608Metric
R16, R17, R24, R25, R30, R32, R41, R42: 5.11k; R_0603_1608Metric
R22, R33, R34, R35, R36, R45, R46, R47, R48: 1.65k; R_0603_1608Metric
U1: IP4220CZ6; SOT457
U2: AP2114; SOT-223
U3: AN431B; SOT-23
U4: CRV1DxxxxSC
U5: DAC084S085C; MSOP-10_3x3mm_Pitch0.5mm
U6, U8: TL084_v; TSSOP-14_4.4x5mm_Pitch0.65mm
U7: LM358; SOIC-8_3.9x4.9mm_Pitch1.27mm
U9: ATSAM4S; LQFP-64_10x10mm_Pitch0.5mm
Y1: 16MHz 18pF; Crystal_HC49-SD_SMD

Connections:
/2.5V: C12.2, C32.1, R12.2, R13.2, R14.1, U3.1 (Cathode), U3.2 (Ref), U5.7 (Vrefin), U9.1 (ADVREF)
/3.3V: C10.1, C11.1, C21.1, C23.1, C25.1, C26.1, C27.1, ERASE.2, R12.1, R13.1, U2.2 (VOUT), U5.1 (Va), U9.7 (VDDIN), U9.18 (VDDIO), U9.45 (VDDIO), U9.58 (VDDIO)
/!SYNC: U5.9 (!SYNC), U9.28 (PA11/PGMM3)
/+9V: C8.1, C13.2, C15.2, C17.2, U4.7 (Vout+), U6.4 (Vcc), U7.8 (V+), U8.4 (Vcc)
/+B: R10.2, R21.1, U6.7 (Out)
/+G: R9.2, R29.1, U6.8 (Out)
/+Int: R7.2, R28.1, U6.1 (Out)
/+R: R8.2, R20.1, U6.14 (Out)
/+X: R3.2, R43.1, U8.14 (Out)
/+Y: R5.2, R44.1, U8.7 (Out)
/-9V: C9.2, C14.2, C16.2, C18.2, U4.5 (Vout-), U6.11 (Vee), U7.4 (V-), U8.11 (Vee)
/-X: R4.2, R37.1, R39.2, U8.8 (Out)
/-Y: R6.2, R38.1, R40.2, U8.1 (Out)
/Amplifiers/Offset: R22.2, R23.1, R33.2, R34.2
/B: R17.2, U5.3 (Voutb)
/D+: P1.3 (D+), R1.2, U1.3 (IO2)
/D-: P1.2 (D-), R2.2, U1.1 (IO1)
/G: R24.2, U5.4 (Voutc)
/Int: R25.2, U5.2 (Vouta)
/Interlock: P2.4, P2.17
/Microcontroller/D+: R1.1, U9.57 (DDP/PB11)
/Microcontroller/D-: R2.1, U9.56 (DDM/PB10)
/Microcontroller/ERASE: ERASE.1, U9.55 (ERASE/PB12)
/Microcontroller/PA22: R47.1, R48.1, U9.14 (PA22/PGMD10/AD9)
/Microcontroller/PA23: R45.1, R46.1, U9.15 (PA23/PGMD11)
/Microcontroller/VDDOUT: C19.1, C20.1, C22.1, C24.1, L3.1, U9.8 (VDDOUT), U9.12 (VDDCORE), U9.24 (VDDCORE), U9.54 (VDDCORE)
/Microcontroller/VDDPLL: C28.1, C30.1, L3.2, U9.64 (VDDPLL)
/Microcontroller/XIN: C29.1, U9.62 (XIN/PGMCK/PB9), Y1.1
/Microcontroller/XOUT: C31.1, U9.61 (XOUT/PB8), Y1.2
/R: R16.2, U5.5 (Voutd)
/SCLK: U5.10 (SCLK), U9.21 (PA14/PGMD2)
/Shutter: R30.2, U9.16 (PA20/PGMD8/AD3)
/Shutter_Out: R11.2, R32.1, U7.7
/VCC: C3.1, C4.1, C6.1, L1.2, L2.1, U1.5 (Vp), U2.3 (VIN)
/X: R35.2, U9.59 (PB13/DAC0)
/Y: R36.2, U9.63 (PB14/DAC1)
GND: C1.2, C2.2, C3.2, C4.2, C6.2, C7.2, C8.2, C9.1, C10.2, C11.2, C12.1, C13.1, C14.1, C15.1, C16.1, C17.1, C18.1, C19.2, C20.2, C21.2, C22.2, C23.2, C24.2, C25.2, C26.2, C27.2, C28.2, C29.2, C30.2, C31.2, C32.2, D1.1 (K), D2.1 (K), P1.4 (GND), P2.8, P2.9, P2.10, P2.11, P2.16, P2.18, P2.19, P2.20, P2.21, P2.22, P2.23, P2.24, P2.25, P2.26 (Shield), R15.2, R18.2, R19.2, R23.2, R26.2, R27.2, R31.1, R41.2, R42.2, U1.2 (GND), U2.1 (GND), U3.3 (Anode), U4.2 (GND), U4.6 (Vout0), U5.6 (GND), U9.2 (GND), U9.17 (GND), U9.40 (TST), U9.46 (GND), U9.60 (GND)
unnamed: C1.1, F1.2, L1.1
unnamed: F1.1, P1.1 (VCC)
unnamed: C2.1, P1.5 (shield)
unnamed: P2.1, R3.1
unnamed: P2.2, R5.1
unnamed: P2.3, R7.1
unnamed: P2.5, R8.1
unnamed: P2.6, R9.1
unnamed: P2.7, R10.1
unnamed: P2.13, R11.1
unnamed: P2.14, R4.1
unnamed: P2.15, R6.1
unnamed: C7.1, L2.2, U4.1 (Vin)

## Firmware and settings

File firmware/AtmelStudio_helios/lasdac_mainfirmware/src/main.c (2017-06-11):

/*
Helios Laser DAC main AS project (for SAM4S2B board)
By Gitle Mikkelsen, Creative Commons Attribution-NonCommercial 4.0 International Public License
gitlem@gmail.com


Required Atmel Software Framework modules:
	DACC - Digital-to-Analog Converter
	Flash
	Generic Board Support (ATSAM4S2B)
	GPIO
	IOPORT
	SPI - Serial Peripheral Interface
	USB Device Vendor Class
	WDT - Watchdog Timer
*/

#include "main.h"

//ENTRY
int main (void)
{
	//allocate memory to buffers
	frameAddress = malloc(MAXFRAMESIZE * 7 + 5);
	newFrameAddress = malloc(MAXFRAMESIZE * 7 + 5);
	usbInterruptBufferAddress = malloc(32);
	
	//start modules
	sysclk_init();
	pmc_disable_all_periph_clk();
	pmc_disable_pllbck();
	dac_init();
	spi_init();
	iopins_init();
	irq_initialize_vectors();
	cpu_irq_enable();
	sleepmgr_init();
	udc_start();
	wdt_setup();
	timer_init();
	flash_init(FLASH_ACCESS_MODE_128, 4);
	
	//set systick higher priority to avoid jitter in playback when processing USB transfers
	NVIC_SetPriority(UDP_IRQn, 2);
	NVIC_SetPriority(SysTick_IRQn, 1);
	
	//default output
	shutter_set(LOW);
	statusled_set(LOW);
	ioport_set_pin_level(PIN_POWERLED, HIGH);
	stop_weak();
	
	sleepmgr_lock_mode(SLEEPMGR_WAIT_FAST);
	
	assign_default_name();
	
	//waiting for interrupts..
	while (1)
	{
		wdt_restart(WDT);
		sleepmgr_enter_sleep();
	}
}

void SysTick_Handler() //systick timer ISR, called for each point
{
	if (playing && !stopFlag && connected)
	{
		if (framePos >= frameSize) //if frame reached the end
		{
			if (newFrameReady)
			{
				//load new frame, switch buffers
				uint8_t* previousFrameAddress = frameAddress;
				frameAddress = newFrameAddress;
				newFrameAddress = previousFrameAddress;
				framePos = 0;
				frameSize = newFrameSize;
				notRepeat = newNotRepeat;
				point_output();
				framePos += 7;
				speed_set(outputSpeed);
				
				update_status();
			}
			else
			{
				if (!notRepeat)
				{
					//loop frame
					framePos = 0;
					point_output();
					framePos += 7;
				}
				else
				{
					stop_weak();
					update_status();
				}
			}
		}
		else
		{
			//output current point
			point_output();
			framePos += 7;
		}
	}
}

void usb_bulk_out_callback(udd_ep_status_t status, iram_size_t length, udd_ep_id_t ep)
{
	UNUSED(ep);
	
	if (!connected)
		return;

	//0-n:	frame data, each point is 12-bit X+Y packed into 24-bit big-endian, 8bit R, 8bit G, 8bit B, 8bit I
	//n:	output rate 16bit little endian
	//n+2:	frame size in points 16bit little endian
	//n+4:	flags
		
	if ( (status == UDD_EP_TRANSFER_OK) && (length <= MAXFRAMESIZE * 7 + 5) && !stopFlag) //if not invalid
	{
		uint16_t numOfPointBytes = length - 5; //from length of received data
		uint16_t numOfPointBytes2 = ((newFrameAddress[numOfPointBytes + 3] << 8) | newFrameAddress[numOfPointBytes + 2]) * 7; //from control bytes
		
		if (numOfPointBytes == numOfPointBytes2) //sanity check, skip frame if conflicting frame size information
		{
			cpu_irq_enter_critical();
				uint8_t flags = newFrameAddress[numOfPointBytes + 4];
				newNotRepeat = (flags & (1 << 1));
				outputSpeed = (newFrameAddress[numOfPointBytes + 1] << 8) | newFrameAddress[numOfPointBytes + 0];			
			
				if ( (!playing) || (flags & (1 << 0)) ) //if frame is to start playing immediately
				{
					uint8_t* previousFrameAddress = frameAddress;
					frameAddress = newFrameAddress;
					newFrameAddress = previousFrameAddress;
					framePos = 0;
					frameSize = numOfPointBytes;
					playing = true;
					notRepeat = newNotRepeat;
					speed_set(outputSpeed);

					update_status();
				} 
				else
				{
					newFrameSize = numOfPointBytes;
					newFrameReady = true;
				}
			cpu_irq_leave_critical();
		}
	}
}

void usb_interrupt_out_callback(udd_ep_status_t status, iram_size_t length, udd_ep_id_t ep)
{
	//LSB: Command
	//MSB: Data

	UNUSED(ep);
	
	if (!connected)
	return;
	
	if (status == UDD_EP_TRANSFER_OK)
	{	
		if (usbInterruptBufferAddress[0] == 0x01)		//STOP
		{
			stop();
		}
		else if (usbInterruptBufferAddress[0] == 0x02)	//SHUTTER
		{
			shutter_set( (usbInterruptBufferAddress[1] != 0) );
		}
		else if (usbInterruptBufferAddress[0] == 0x03)	//STATUS/NEW FRAME POLL (deprecated)
		{
			uint8_t transfer[2] = {0x83, 0};
			if (!newFrameReady)
			{
				udi_vendor_bulk_out_run(newFrameAddress, MAXFRAMESIZE * 7 + 5, usb_bulk_out_callback);
				transfer[1] = 1;	
			}
			
			udi_vendor_interrupt_in_run(&transfer[0], 2, NULL);
		}
		else if (usbInterruptBufferAddress[0] == 0x04)	//GET FIRMWARE VERSION
		{
			uint8_t transfer[5] = {0x84,(uint8_t)(FIRMWARE_VERSION >> 0),
										(uint8_t)(FIRMWARE_VERSION >> 8),
										(uint8_t)(FIRMWARE_VERSION >> 16),
										(uint8_t)(FIRMWARE_VERSION >> 24)};
										
			udi_vendor_interrupt_in_run(&transfer[0], 5, NULL);
		}
		else if (usbInterruptBufferAddress[0] == 0x05)	//GET NAME
		{
			uint8_t transfer[32];
			transfer[0] = 0x85;
			uint32_t flashBuf[32];
			flash_read_user_signature(&flashBuf[0], 32);
			int i;
			for (i = 0; i < 31; i++)
			{
				transfer[1+i] = flashBuf[i];
				if (flashBuf[i] == 0)
					break;
			}
			
			udi_vendor_interrupt_in_run(&transfer[0], 32, NULL);
		}
		else if (usbInterruptBufferAddress[0] == 0x06)	//WRITE NAME
		{
			uint32_t flash[31];
			int i;
			for (i = 0; i < 31; i++)
			{
				flash[i] = (uint32_t)usbInterruptBufferAddress[1+i];
			}
			flash_erase_user_signature();
			flash_write_user_signature((void*)&flash[0], 32);
		}
		else if (usbInterruptBufferAddress[0] == 0x07)	//GET SDK VERSION
		{
			sdkVersion = usbInterruptBufferAddress[1];
		}
		else if (usbInterruptBufferAddress[0] == 0xDE)	//ERASE GPNVM BIT, BOOT TO FIRMWARE UPDATE BOOTLOADER
		{
			stop_weak();
			flash_clear_gpnvm(1);
			while (1); //watchdog should restart mcu
		}
	}
	
	udi_vendor_interrupt_out_run(usbInterruptBufferAddress, 32, usb_interrupt_out_callback);
}


inline void point_output(void) //sends point data to the DACs, data is point number "framePos" in buffer "frameAddress".
{
	uint8_t* currentPoint = frameAddress + framePos;
	
	if ((dacc_get_interrupt_status(DACC) & DACC_ISR_TXRDY) == DACC_ISR_TXRDY) //if DAC ready
	{
		posData = ((((currentPoint[0] << 4) | (currentPoint[1] >> 4)) << 16)) | ((1 << 12) | ((currentPoint[1] & 0x0F) << 8) | currentPoint[2]);
		dacc_write_conversion_data(DACC, posData );
	}
	
	spi_write(SPI, (currentPoint[3] << 4) | (0b1101 << 12), 0, 0); //R
	spi_write(SPI, (currentPoint[4] << 4) | (0b1001 << 12), 0, 0); //G
	spi_write(SPI, (currentPoint[5] << 4) | (0b0101 << 12), 0, 0); //B
	spi_write(SPI, (currentPoint[6] << 4) | (0b0001 << 12), 0, 0); //I
	
	statusled_set( (currentPoint[6] != 0) ); //turn on status led if not blanked
}

void stop_weak(void) //outputs a blanked and centered point and stops playback
{
	SysTick->CTRL = SysTick_CTRL_CLKSOURCE_Msk; //disable systick IRQ
	playing = false;
	framePos = 0;
	update_status();
	statusled_set(LOW);
	
	spi_write(SPI, (0b0010 << 12), 0, 0); //blank all colors
}

void stop(void) //outputs a blanked and centered point and stops playback
{
	stopFlag = true;
	stop_weak();
	tc_start(TC0, 0); //set timer for delayed stop in case new unwanted frame is on the way over USB
}

//timer ISR for delayed stop
void TC0_Handler(void)
{
	uint32_t dummy;
	dummy = tc_get_status(TC0, 0);
	UNUSED(dummy);
	
	tc_stop(TC0,0);
	
	stop_weak();
	
	if ((dacc_get_interrupt_status(DACC) & DACC_ISR_TXRDY) == DACC_ISR_TXRDY) //if DAC ready
	{
		posData = (0x800 << 16) | ((1 << 12) | 0x800);
		dacc_write_conversion_data(DACC, posData ); //center XY
	}
	
	stopFlag = false;
	
	if (connected)
		update_status();
}

void speed_set(uint32_t rate) //set the output speed in points per second
{
	if (!connected)
		return; 
		
	if (rate > MAXSPEED)
		rate = MAXSPEED;
	else if (rate < MINSPEED)
		rate = MINSPEED;
	outputSpeed = rate;
	SysTick_Config( (sysclk_get_cpu_hz() / rate) + 1);
	NVIC_SetPriority(SysTick_IRQn, 1);
}

int callback_vendor_enable(void) //usb connection opened, preparing for activity
{	
	connected = true;
	stop_weak();
	
	sleepmgr_unlock_mode(SLEEPMGR_WAIT_FAST);
	sleepmgr_lock_mode(SLEEPMGR_ACTIVE);
	
	udi_vendor_interrupt_out_run(usbInterruptBufferAddress, 32, usb_interrupt_out_callback);
	udi_vendor_bulk_out_run(newFrameAddress, MAXFRAMESIZE * 7 + 5, usb_bulk_out_callback);
	
	return 1;
}

void callback_vendor_disable(void) //usb connection closed, sleeping to save power
{
	connected = false;
	stop();
	
	sleepmgr_unlock_mode(SLEEPMGR_ACTIVE);
	sleepmgr_lock_mode(SLEEPMGR_WAIT_FAST);
}

inline void shutter_set(bool level)
{
	ioport_set_pin_level(PIN_SHUTTER, level);
}

inline void statusled_set(bool level)
{
	ioport_set_pin_level(PIN_STATUSLED, level);
}

//INIT FUNCTIONS:

void iopins_init(void) //setup io pins config
{
	ioport_set_pin_dir(PIN_SHUTTER, IOPORT_DIR_OUTPUT);
	ioport_set_pin_dir(PIN_STATUSLED, IOPORT_DIR_OUTPUT);
	ioport_set_pin_dir(PIN_POWERLED, IOPORT_DIR_OUTPUT);
	
	//ioport_set_pin_dir(PIN_DEBUG1, IOPORT_DIR_OUTPUT);
	//ioport_set_pin_level(PIN_DEBUG1, LOW);
	//ioport_set_pin_dir(PIN_DEBUG2, IOPORT_DIR_OUTPUT);
	//ioport_set_pin_level(PIN_DEBUG2, LOW);
}

void spi_init(void) //setup SPI for DAC084S085
{
	gpio_configure_pin(SPI_MISO_GPIO, SPI_MISO_FLAGS);
	gpio_configure_pin(SPI_MOSI_GPIO, SPI_MOSI_FLAGS);
	gpio_configure_pin(SPI_SPCK_GPIO, SPI_SPCK_FLAGS);
	gpio_configure_pin(SPI_NPCS0_GPIO, SPI_NPCS0_FLAGS);
	spi_enable_clock(SPI);
	spi_disable(SPI);
	spi_reset(SPI);
	spi_set_master_mode(SPI);
	spi_set_fixed_peripheral_select(SPI);
	spi_disable_mode_fault_detect(SPI);
	spi_configure_cs_behavior(SPI, 0, SPI_CS_RISE_FORCED);
	spi_set_delay_between_chip_select(SPI, 6);
	spi_set_peripheral_chip_select_value(SPI, spi_get_pcs(0));
	spi_set_clock_polarity(SPI, 0, 0);
	spi_set_clock_phase(SPI, 0, 0);
	spi_set_bits_per_transfer(SPI, 0, SPI_CSR_BITS_16_BIT);
	spi_set_baudrate_div(SPI, 0, 5 ); //112MHz / 5 = 22.4 MHz
	spi_set_transfer_delay(SPI, 0, 0, 0);
	spi_enable(SPI);
}

void dac_init(void) //setup sam internal DAC controller
{
	sysclk_enable_peripheral_clock(ID_DACC);
	dacc_reset(DACC);
	dacc_enable_channel(DACC, 0);
	dacc_enable_channel(DACC, 1);
	dacc_set_transfer_mode(DACC, 1);
	dacc_enable_flexible_selection(DACC);
}

void timer_init(void) //set up timer counter for delayed stop
{
	pmc_enable_periph_clk(ID_TC0);
	uint32_t timerDiv;
	uint32_t timerClkSource;
	uint32_t timerFreq = 10; // 1s/10 = 100ms
	uint32_t sysClkFreq = sysclk_get_cpu_hz();
	tc_find_mck_divisor(timerFreq, sysClkFreq, &timerDiv, &timerClkSource, sysClkFreq);
	tc_init(TC0, 0, timerClkSource | TC_CMR_CPCTRG | TC_CMR_CPCSTOP);
	stopTimerCounts = (sysClkFreq/timerDiv)/timerFreq;
	NVIC_DisableIRQ(TC0_IRQn);
	NVIC_ClearPendingIRQ(TC0_IRQn);
	NVIC_SetPriority(TC0_IRQn,0);
	NVIC_EnableIRQ(TC0_IRQn);
	tc_enable_interrupt(TC0, 0, TC_IER_CPCS);
	tc_write_rc(TC0, 0, stopTimerCounts);
}

void wdt_setup() //setup watchdog to trigger a reset at WDT_PERIOD ms inactivity
{
	uint32_t timeout_value = wdt_get_timeout_value(WDT_PERIOD * 1000, BOARD_FREQ_SLCK_XTAL);
	uint32_t wdt_mode = WDT_MR_WDRSTEN | WDT_MR_WDDBGHLT | WDT_MR_WDIDLEHLT;
	wdt_init(WDT, wdt_mode, timeout_value, timeout_value);
}

void assign_default_name() //on first ever boot, assign default name and store to flash
{
	uint32_t flash[16];
	flash_read_user_signature(&flash[0], 16);
	if (flash[0] == 0xFFFFFFFF) //factory value
	{
		uint32_t unique[4];
		flash_read_unique_id(&unique[0], 4);
		char name[16];
		sprintf(&name[0], "Helios %ld", unique[3]);
		int i;
		for (i = 0; i < 16; i++)
		{
			flash[i] = (uint32_t)name[i];
			if (name[i] == 0)
				break;
		}
		flash_erase_user_signature();
		flash_write_user_signature((void*)&flash[0], 16);
	}
}

inline void update_status() //ready to receive new frame
{
	newFrameReady = false;
	udi_vendor_bulk_out_run(newFrameAddress, MAXFRAMESIZE * 7 + 5, usb_bulk_out_callback);
}

// Below is all to make Windows automatically install driver when plugged in
// Credits: https://github.com/cjameshuff/m1k-fw/

static USB_MicrosoftCompatibleDescriptor msft_compatible = {
	.dwLength = sizeof(USB_MicrosoftCompatibleDescriptor) +
	1*sizeof(USB_MicrosoftCompatibleDescriptor_Interface),
	.bcdVersion = 0x0100,
	.wIndex = 0x0004,
	.bCount = 1,
	.reserved = {0, 0, 0, 0, 0, 0, 0},
	.interfaces = {
		{
			.bFirstInterfaceNumber = 0,
			.reserved1 = 0,
			.compatibleID = "WINUSB\0\0",
			.subCompatibleID = {0, 0, 0, 0, 0, 0, 0, 0},
			.reserved2 = {0, 0, 0, 0, 0, 0},
		}
	}
};

// WCID configuration information
// Hooked into UDC via UDC_GET_EXTRA_STRING #define.
bool msft_string_handle(void) {
	uint8_t udi_msft_magic[] = "MSFT1000";

	struct extra_strings_desc_t{
		usb_str_desc_t header;
		le16_t string[sizeof(udi_msft_magic)];
	};

	static UDC_DESC_STORAGE struct extra_strings_desc_t extra_strings_desc = {
		.header.bDescriptorType = USB_DT_STRING
	};

	uint8_t i;
	uint8_t *str;
	uint8_t str_lgt=0;

	if ((udd_g_ctrlreq.req.wValue & 0xff) == 0xEE) {
		str_lgt = sizeof(udi_msft_magic)-1;
		str = udi_msft_magic;
	}
	else {
		return false;
	}

	if (str_lgt!=0) {
		for( i=0; i<str_lgt; i++) {
			extra_strings_desc.string[i] = cpu_to_le16((le16_t)str[i]);
		}
		extra_strings_desc.header.bLength = 2+ (str_lgt)*2;
		udd_g_ctrlreq.payload_size = extra_strings_desc.header.bLength;
		udd_g_ctrlreq.payload = (uint8_t *) &extra_strings_desc;
	}

	// if the string is larger than request length, then cut it
	if (udd_g_ctrlreq.payload_size > udd_g_ctrlreq.req.wLength) {
		udd_g_ctrlreq.payload_size = udd_g_ctrlreq.req.wLength;
	}
	return true;
}

bool usb_device_specific_request(void) {
	uint8_t* ptr = 0;
	uint16_t size = 0;
	
	if (Udd_setup_type() == USB_REQ_TYPE_VENDOR) {
		switch (udd_g_ctrlreq.req.bRequest) {
			/// windows compatible ID handling for auto install
			case 0x30: {
				if (udd_g_ctrlreq.req.wIndex == 0x04) {
					ptr = (uint8_t*)&msft_compatible;
					size = (udd_g_ctrlreq.req.wLength);
					if (size > msft_compatible.dwLength) {
						size = msft_compatible.dwLength;
					}
					
				}
				else {
					return false;
				}
				break;
			}
		}
	}
	udd_g_ctrlreq.payload_size = size;
	if ( size == 0 ) {
		udd_g_ctrlreq.callback = 0;
		udd_g_ctrlreq.over_under_run = 0;
	}
	else {
		udd_g_ctrlreq.payload = ptr;
	}
	return true;
}

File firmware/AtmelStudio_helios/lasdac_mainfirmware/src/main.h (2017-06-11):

/*
Helios Laser DAC main AS project (for SAM4S2B board)
By Gitle Mikkelsen, Creative Commons Attribution-NonCommercial 4.0 International Public License
gitlem@gmail.com


Required Atmel Software Framework modules:
	DACC - Digital-to-Analog Converter
	Flash
	Generic Board Support (ATSAM4S2B)
	GPIO
	IOPORT
	SPI - Serial Peripheral Interface
	USB Device Vendor Class
	WDT - Watchdog Timer
*/

#ifndef MAIN_H_
#define MAIN_H_

#include "asf.h"
#include <malloc.h>
#include <string.h> //for memcpy

//macros
#define FIRMWARE_VERSION 6			//firmware version number
#define MAXSPEED 0xFFFF				//in pps	(65535)
#define MINSPEED 7					//in pps
#define MAXFRAMESIZE 0x1000			//in points (4096)
#define WDT_PERIOD 500				//watchdog timer period in ms

//global variables
uint16_t frameSize = 0;					//size of frame buffer in points
uint16_t framePos = 0;					//current position in frame in points
uint16_t newFrameSize = 0;				//incoming frame total size in points
bool newFrameReady = false;				//signals a new frame has been received and is ready to play when the current one ends
bool playing = false;					//signals a point should be output next systick
uint32_t outputSpeed = 20000;			//points per second rate
bool notRepeat = true;					//signals that current frame should be only be played once even if no new frame arrives before it ends
bool newNotRepeat = true;				//notRepeat value for pending frame
bool stopFlag = false;					//delayed stop in effect, won't write new frame during this period
uint32_t stopTimerCounts;				//num of cycles to delay stop, defined in timer_init
uint32_t posData;						//XY position data
uint8_t sdkVersion = 4;					//host driver version, for backwards compatibility 
bool connected = false;					//connected to host driver or not
bool debugVal = LOW;

uint8_t* frameAddress;					//frame currently being played
uint8_t* newFrameAddress;				//buffer to receive usb transfer with frame
uint8_t* usbInterruptBufferAddress;		//usb interrupt transfer buffer

//functions
void speed_set(uint32_t rate);			//sets up the systick interrupt to match the playback rate (in pps)
void shutter_set(bool level);			//sets the shutter level
void statusled_set(bool level);			//sets the status LED level
void point_output(void);				//outputs current point (controlled by framePos and frameAddress variables)
void stop(void);						//blanks and centers output and stops playback (plus timed safety period)
void stop_weak(void);					//blanks and centers output and stops playback
void spi_init(void);					//sets up SPI module
void dac_init(void);					//sets up DACC module
void iopins_init(void);					//sets up IO module and pins
void timer_init(void);					//sets up TC0 module for stop delay timer
void wdt_setup(void);					//initialize watchdog timer
void assign_default_name(void);			//on first ever boot, assign default name and store to flash
void update_status(void);				//sends the new status to the host driver

//USB transfer interrupts
void usb_bulk_out_callback(udd_ep_status_t status, iram_size_t length, udd_ep_id_t ep);
void usb_interrupt_out_callback(udd_ep_status_t status, iram_size_t length, udd_ep_id_t ep);


// Below is part of setup to make Windows automatically install driver when plugged in
// Credits: https://github.com/cjameshuff/m1k-fw

/// Microsoft WCID descriptor
typedef struct USB_MicrosoftCompatibleDescriptor_Interface {
	uint8_t bFirstInterfaceNumber;
	uint8_t reserved1;
	uint8_t compatibleID[8];
	uint8_t subCompatibleID[8];
	uint8_t reserved2[6];
} __attribute__((packed)) USB_MicrosoftCompatibleDescriptor_Interface;

typedef struct USB_MicrosoftCompatibleDescriptor {
	uint32_t dwLength;
	uint16_t bcdVersion;
	uint16_t wIndex;
	uint8_t bCount;
	uint8_t reserved[7];
	USB_MicrosoftCompatibleDescriptor_Interface interfaces[];
} __attribute__((packed)) USB_MicrosoftCompatibleDescriptor;

#endif /* MAIN_H_ */

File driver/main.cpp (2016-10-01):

/*
Driver API for Helios Laser DACs
By Gitle Mikkelsen, Creative Commons Attribution-NonCommercial 4.0 International Public License

See main.h for documentation

Dependencies: 
Libusb 1.0 (GNU Lesser General Public License, see libusb.h)
HeliosDAC class (part of this driver)
*/

#include "main.h"


int OpenDevices()
{
	CloseDevices();

	dacController = new HeliosDac();

	int result = dacController->OpenDevices();

	if (result <= 0)
		delete dacController;
	else
		inited = true;

	printf("OpenDevices() found: %d", result);

	return result;
}


int WriteFrame(int dacNum, int pps, uint8_t flags, HeliosPoint* points, int numOfPoints)
{
	if ((!inited) || (points == NULL))
		return 0;
	if ((numOfPoints > HELIOS_MAX_POINTS) || (pps > HELIOS_MAX_RATE) || (pps < HELIOS_MIN_RATE))
		return 0;

	//prepare frame buffer
	uint8_t frameBuffer[HELIOS_MAX_POINTS * 7 + 5];
	int bufPos = 0;
	for (int i = 0; i < numOfPoints; i++)
	{
		frameBuffer[bufPos++] = (points[i].x >> 4);
		frameBuffer[bufPos++] = ((points[i].x & 0x0F) << 4) | (points[i].y >> 8);
		frameBuffer[bufPos++] = (points[i].y & 0xFF);
		frameBuffer[bufPos++] = points[i].r;
		frameBuffer[bufPos++] = points[i].g;
		frameBuffer[bufPos++] = points[i].b;
		frameBuffer[bufPos++] = points[i].i;
	}
	frameBuffer[bufPos++] = (pps & 0xFF);
	frameBuffer[bufPos++] = (pps >> 8);
	frameBuffer[bufPos++] = (numOfPoints & 0xFF);
	frameBuffer[bufPos++] = (numOfPoints >> 8);
	frameBuffer[bufPos++] = flags;

	return dacController->SendFrame(dacNum, &frameBuffer[0], bufPos);
}

int Stop(int dacNum)
{
	if (!inited)
		return 0;

	uint8_t ctrlBuffer[2] = { 0x01, 0 };
	if (dacController->SendControl(dacNum, &ctrlBuffer[0], false) == (uint16_t)true)
		return 1;
	return 0;
}


int GetName(int dacNum, char* name)
{
	if (!inited)
		return 0;

	memcpy(name, "Helios ", 8);
	name[7] = (char)((int)(dacNum >= 10) + 48);
	name[8] = (char)((int)(dacNum % 10) + 48);
	name[9] = '\0';

	return 1;
}


int GetStatus(int dacNum)
{
	if (!inited)
		return -1;

	uint8_t ctrlBuffer[2] = { 0x03, 0 };
	uint16_t result = dacController->SendControl(dacNum, &ctrlBuffer[0], true);

	if ((result >> 8) == 0x83) //if received control byte is as expected
	{
		if (result & 1) //if dac is ready
			return 1;
		else
			return 0;
	}
	else
		return -1;
}


int SetShutter(int dacNum, bool value)
{
	if (!inited)
		return 0;

	uint8_t ctrlBuffer[2] = { 0x02, value };
	return dacController->SendControl(dacNum, &ctrlBuffer[0], false);
}

int GetFirmwareVersion(int dacNum)
{
	if (!inited)
		return -1;

	uint8_t ctrlBuffer[2] = { 0x04, 0 };
	uint16_t result = dacController->SendControl(dacNum, &ctrlBuffer[0], true);

	if ((result >> 8) == 0x84) //if received control byte is as expected
		return (result & 0xFF);
	else
		return -1;
}


int CloseDevices()
{
	if (inited)
	{
		inited = false;
		delete dacController;
		return 1;
	}
	else
		return 0;
}


//Below is OLSC implementation
//OLSC API is designed by Chris Favreau, MIT License

OLSC_API int __stdcall OLSC_GetAPIVersion(void)
{
	return OPEN_LASER_SHOW_DEVICE_API_VERSION;
}

OLSC_API int __stdcall OLSC_GetInterfaceName(char* pString)
{
	memcpy(pString, "Helios", 7);
	return OLSC_ERROR_SUCCESS;
}

OLSC_API int __stdcall OLSC_Initialize(void)
{
	return OpenDevices();
}

OLSC_API int __stdcall OLSC_Shutdown(void)
{
	CloseDevices();
	return OLSC_ERROR_SUCCESS;
}

OLSC_API int __stdcall OLSC_GetDeviceCount(void)
{
	if (!inited)
		return OLSC_ERROR_NONE;
	else
		return dacController->numOfDevices;
}

OLSC_API int __stdcall OLSC_GetDeviceCapabilities(int device_number, struct LASER_SHOW_DEVICE_CAPABILITIES& device_capabilities)
{
	if (!inited)
		return OLSC_ERROR_NONE;

	device_capabilities.color_resolution = 8;
	device_capabilities.xy_resolution = 12;
	device_capabilities.has_dmx_in = false;
	device_capabilities.has_dmx_out = false;
	device_capabilities.has_ttl_in = false;
	device_capabilities.has_ttl_out = false;
	device_capabilities.max_frame_size = HELIOS_MAX_POINTS;
	device_capabilities.max_speed = HELIOS_MAX_RATE;
	device_capabilities.min_frame_size = 1;
	device_capabilities.min_speed = HELIOS_MIN_RATE;
	GetName(device_number, &device_capabilities.name[0]);
	device_capabilities.uses_callbacks = false;
	device_capabilities.version_major = 1;
	device_capabilities.version_minor = 0;

	return OLSC_ERROR_SUCCESS;
}

OLSC_API int __stdcall OLSC_GetLastErrorNumber(int device_number, int& number, char* string_pointer, int string_length)
{
	//not supported yet
	return OLSC_ERROR_NONE;
}

OLSC_API int __stdcall OLSC_Play(int device_number)
{
	//not supported yet, use OLSC_WriteFrame()
	return OLSC_ERROR_NONE;
}

OLSC_API int __stdcall OLSC_Pause(int device_number)
{
	return Stop(device_number);
}

OLSC_API int __stdcall OLSC_Shutter(int device_number, int state)
{
	return SetShutter(device_number, !state); //OLSC uses 0 as ON for some reason
}

OLSC_API int __stdcall OLSC_WriteFrameEx(int device_number, int display_speed, int point_count, struct LASER_SHOW_DEVICE_POINT *points)
{
	struct LASER_SHOW_DEVICE_FRAME frame;
	frame.display_speed = display_speed;
	frame.point_count = point_count;
	frame.points = points;

	return OLSC_WriteFrame(device_number, frame);
}

OLSC_API int __stdcall OLSC_WriteFrame(int device_number, struct LASER_SHOW_DEVICE_FRAME frame)
{
	if (!inited)
		return OLSC_ERROR_FAILED;
	if ((frame.point_count > HELIOS_MAX_POINTS) || (frame.display_speed > HELIOS_MAX_RATE) || (frame.display_speed < HELIOS_MIN_RATE))
		return OLSC_ERROR_INVALID_PARAMETER;

	//prepare frame buffer, 16-bit values are explicitly split into 8-bit to avoid endianness-problems across any architecture
	uint8_t frameBuffer[HELIOS_MAX_POINTS * 7 + 5];
	int bufPos = 0;
	for (int i = 0; i < frame.point_count; i++)
	{
		frameBuffer[bufPos++] = (frame.points[i].x >> 8);
		frameBuffer[bufPos++] = (((frame.points[i].x >> 4) & 0xF) << 4) + (frame.points[i].y >> 12);
		frameBuffer[bufPos++] = ((frame.points[i].y >> 4) & 0xFF);
		frameBuffer[bufPos++] = (uint8_t)frame.points[i].r;
		frameBuffer[bufPos++] = (uint8_t)frame.points[i].g;
		frameBuffer[bufPos++] = (uint8_t)frame.points[i].b;
		frameBuffer[bufPos++] = (uint8_t)frame.points[i].i;
	}
	frameBuffer[bufPos++] = (frame.display_speed & 0xFF);
	frameBuffer[bufPos++] = (frame.display_speed >> 8);
	frameBuffer[bufPos++] = (frame.point_count & 0xFF);
	frameBuffer[bufPos++] = (frame.point_count >> 8);
	frameBuffer[bufPos++] = 0;

	
	//send frame to dac
	return dacController->SendFrame(device_number, &frameBuffer[0], bufPos);
}

OLSC_API int __stdcall OLSC_GetStatus(int device_number, DWORD& status)
{
	if (!inited)
		return OLSC_ERROR_NONE;

	uint8_t statusResult = GetStatus(device_number);
	if (statusResult == -1)
		return OLSC_ERROR_FAILED;

	if (statusResult == 1)
	{
		status = OLSC_STATUS_BUFFER_EMPTY;
	}
	else
		status = OLSC_STATUS_BUFFER_FULL;
	
	return OLSC_ERROR_SUCCESS;
}
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

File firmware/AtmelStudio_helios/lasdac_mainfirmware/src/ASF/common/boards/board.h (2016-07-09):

/**
 * \file
 *
 * \brief Standard board header file.
 *
 * This file includes the appropriate board header file according to the
 * defined board (parameter BOARD).
 *
 * Copyright (c) 2009-2015 Atmel Corporation. All rights reserved.
 *
 * \asf_license_start
 *
 * \page License
 *
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
 * 3. The name of Atmel may not be used to endorse or promote products derived
 *    from this software without specific prior written permission.
 *
 * 4. This software may only be redistributed and used in connection with an
 *    Atmel microcontroller product.
 *
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
 * \asf_license_stop
 *
 */
/*
 * Support and FAQ: visit <a href="http://www.atmel.com/design-support/">Atmel Support</a>
 */

#ifndef _BOARD_H_
#define _BOARD_H_

/**
 * \defgroup group_common_boards Generic board support
 *
 * The generic board support module includes board-specific definitions
 * and function prototypes, such as the board initialization function.
 *
 * \{
 */

#include "compiler.h"

#ifdef __cplusplus
extern "C" {
#endif


/*! \name Base Boards
 */
//! @{
#define EVK1100                     1  //!< AT32UC3A EVK1100 board.
#define EVK1101                     2  //!< AT32UC3B EVK1101 board.
#define UC3C_EK                     3  //!< AT32UC3C UC3C-EK board.
#define EVK1104                     4  //!< AT32UC3A3 EVK1104 board.
#define EVK1105                     5  //!< AT32UC3A EVK1105 board.
#define STK600_RCUC3L0              6  //!< STK600 RCUC3L0 board.
#define UC3L_EK                     7  //!< AT32UC3L-EK board.
#define XPLAIN                      8  //!< ATxmega128A1 Xplain board.
#define STK600_RC064X              10  //!< ATxmega256A3 STK600 board.
#define STK600_RC100X              11  //!< ATxmega128A1 STK600 board.
#define UC3_A3_XPLAINED            13  //!< ATUC3A3 UC3-A3 Xplained board.
#define UC3_L0_XPLAINED            15  //!< ATUC3L0 UC3-L0 Xplained board.
#define STK600_RCUC3D              16  //!< STK600 RCUC3D board.
#define STK600_RCUC3C0             17  //!< STK600 RCUC3C board.
#define XMEGA_B1_XPLAINED          18  //!< ATxmega128B1 Xplained board.
#define XMEGA_A1_XPLAINED          19  //!< ATxmega128A1 Xplain-A1 board.
#define XMEGA_A1U_XPLAINED_PRO     20  //!< ATxmega128A1U XMEGA-A1U Xplained Pro board.
#define STK600_RCUC3L4             21  //!< ATUCL4 STK600 board.
#define UC3_L0_XPLAINED_BC         22  //!< ATUC3L0 UC3-L0 Xplained board controller board.
#define MEGA1284P_XPLAINED_BC      23  //!< ATmega1284P-Xplained board controller board.
#define STK600_RC044X              24  //!< STK600 with RC044X routing card board.
#define STK600_RCUC3B0             25  //!< STK600 RCUC3B0 board.
#define UC3_L0_QT600               26  //!< QT600 UC3L0 MCU board.
#define XMEGA_A3BU_XPLAINED        27  //!< ATxmega256A3BU Xplained board.
#define STK600_RC064X_LCDX         28  //!< XMEGAB3 STK600 RC064X LCDX board.
#define STK600_RC100X_LCDX         29  //!< XMEGAB1 STK600 RC100X LCDX board.
#define UC3B_BOARD_CONTROLLER      30  //!< AT32UC3B1 board controller for Atmel boards.
#define RZ600                      31  //!< AT32UC3A RZ600 MCU board.
#define SAM3S_EK                   32  //!< SAM3S-EK board.
#define SAM3U_EK                   33  //!< SAM3U-EK board.
#define SAM3X_EK                   34  //!< SAM3X-EK board.
#define SAM3N_EK                   35  //!< SAM3N-EK board.
#define SAM3S_EK2                  36  //!< SAM3S-EK2 board.
#define SAM4S_EK                   37  //!< SAM4S-EK board.
#define STK600_RCUC3A0             38  //!< STK600 RCUC3A0 board.
#define STK600_MEGA                39  //!< STK600 MEGA board.
#define MEGA_1284P_XPLAINED        40  //!< ATmega1284P Xplained board.
#define SAM4S_XPLAINED             41  //!< SAM4S Xplained board.
#define ATXMEGA128A1_QT600         42  //!< QT600 ATXMEGA128A1 MCU board.
#define ARDUINO_DUE_X              43  //!< Arduino Due/X board.
#define STK600_RCUC3L3             44  //!< ATUCL3 STK600 board.
#define SAM4L_EK                   45  //!< SAM4L-EK board.
#define STK600_MEGA_RF             46  //!< STK600 MEGA RF EVK board.
#define XMEGA_C3_XPLAINED          47  //!< ATxmega384C3 Xplained board.
#define STK600_RC032X              48  //!< STK600 with RC032X routing card board.
#define SAM4S_EK2                  49  //!< SAM4S-EK2 board.
#define XMEGA_E5_XPLAINED          50  //!< ATxmega32E5 Xplained board.
#define SAM4E_EK                   51  //!< SAM4E-EK board.
#define ATMEGA256RFR2_XPLAINED_PRO 52  //!< ATmega256RFR2 Xplained Pro board.
#define SAM4S_XPLAINED_PRO         53  //!< SAM4S Xplained Pro board.
#define SAM4L_XPLAINED_PRO         54  //!< SAM4L Xplained Pro board.
#define ATMEGA256RFR2_ZIGBIT       55  //!< ATmega256RFR2 zigbit.
#define XMEGA_RF233_ZIGBIT         56  //!< ATxmega256A3U with AT86RF233 Zigbit.
#define XMEGA_RF212B_ZIGBIT        57  //!< ATxmega256A3U with AT86RF212B Zigbit.
#define SAM4S_WPIR_RD              58  //!< SAM4S-WPIR-RD board.
#define SAMD20_XPLAINED_PRO        59  //!< SAM D20 Xplained Pro board.
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

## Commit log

2016-06-30 add kicad project
    [Amplifiers.sch, DAC.sch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]
2016-07-09 temp driver and 7byte point structure firmware
2016-07-14 driver finished but untested
    [Amplifiers.sch, DAC.sch, Helios.kicad_pcb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]
2016-07-18 GPIO signal wiring and USB IDs
    [Helios.kicad_pcb]
2016-07-23 redone pcb, driver and firmware working-ish
    [Amplifiers.sch, DAC.sch, Helios.kicad_pcb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]
2016-07-26 rev 1.1 pcb final
    [Amplifiers.sch, DAC.sch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]
2016-07-29 fix BOM error
    [HeliosBOM.xlsx]
2016-08-03 experimenting with driver
2016-08-04 capacitors wrong polarity
    [Amplifiers.sch, DAC.sch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]
2016-08-08 improve driver
2016-08-13 fix color amps error
    [Amplifiers.sch, DAC.sch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]
2016-08-15 removed uneccessary resistors
    [Amplifiers.sch, Helios.kicad_pcb]
2016-09-17 firmware and driver fixes, working completely?
    [conf_board.h, main.c, main.cpp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]
2016-09-24 fix Stop() bug and winusb auto install working
    [main.c, main.cpp, main.h]
2016-09-27 OLSC compatible driver
2016-09-29 media folder and tweaking interrupt transfers
2016-09-30 added delayed stop timer for reliability
2016-10-07 reorganize folders
    [Amplifiers.sch, DAC.sch, Helios.kicad_pcb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]
2016-10-15 driver updated to support firmware v2
2016-10-16 trying to fix backwards comp.
    [main.cpp]
2016-12-21 optionally flipped X axis
2017-01-12 improved writing of point to dacs, plus shorter watchdog timer
    [main.c, main.h]
2017-01-15 fixed jitter
2017-02-26 mostly finished firmware+sdk v5 but bugs remain
    [main.c]
2017-03-12 fixed thread not quitting when dac unplugged while playing, + cleanup
2017-06-09 revert to explicit status query, + cleanup
    [main.c, main.h]
2017-06-11 fix bug causing some frame sizes to fail + erronous flag constants in header
    [main.c, main.h]
2018-04-09 EzAudDac compatible api in driver
2018-04-27 Added ARM & ARM64 support for Windows
2018-12-06 Use correct device number in call to WriteFrame()
2019-05-19 fix some outdated schematics
    [Amplifiers.sch, DAC.sch, Helios--BOM2018.3.17.xlsx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]
2020-11-21 Continued on .NET driver, and fixed a compile error in c++ driver in windows
2020-11-22 More work on dotnet driver.
2021-01-29 Fix windows python example having too many points in a frame
2022-06-09 Automatically open shutter when sending a frame
2022-08-21 Fix wrong frame buffer array size in dotnet implementation (but library still not working in windows)
2023-03-31 Fix dangling libusb thread after closing devices
2024-11-04 Integrated IDN support (#28)
    * Include IDN files
    * Basic IDN support working
    * Changing strategy for variable resolution frames
    * Legacy format IDN frame writing tested to work
    * Move code to correct place
    * Explicitly set shutter on C# example code
    * Fix bugs in new IDN driver
    * Add simulated status timing to IDN driver for compatibility
    * unix libusb libraries copied to dotnet folder for clarity
    * Add support for getting firmware version and renaming IDN dacs
    * Add support for renaming IDN DACs and fix bugs
    * Separate max/min frame specs for USB and IDN, with subsampling for compatibility
    * Modernized cpp app example, and fixed some bugs in IDN driver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
2025-01-03 Change IDN to wave mode, and more (#29)
    * Started switch to IDN wave mode, but buggy
    * Improve simulated timing
    * Fix possible wave packet with too low point count.
    * Misc polish
    * Improved but still not good enough jitter. Also fix duplicate servers based on unit-id
    * Checkpoint before trying ring buffer
    * Major refactor, glitchy still
    * Small tweaks. Glitchy, probably race condition
    * Finally working well
    * Polish
    * Added more functions for differentiating between USB and IDN devices
    * Protect against too small frames
    * polish
    * Fix possible crash when closing device, and unix timing
    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
2025-02-11 Remove USB device threading from default flags
2025-11-02 Don't verify connection during rescan if USB device was recently active
2025-12-08 switch to new PSU on PCB. Fix bug in sdk example c++ app
    [Amplifiers.kicad_sch, DAC.kicad_sch, Helios--BOM2018.3.17.xlsx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]
2025-12-22 PCB 1.2
    [Helios-B_Cu.gbr, Helios-B_Mask.gbr, Helios-Edge_Cuts.gbr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]
2026-01-01 Improve comments in driver and example code
2026-01-26 Fix bug with D1 in pcb
    [Helios.kicad_pcb]
2026-03-11 Minor changes to fix compilation on MacOS (#35)
    * Minor changes to fix compilation on MacOS
    * Revert macOS specific packet handling
    Removed macOS specific handling for oversized UDP datagrams and adjusted logic for increasing max UDP packet size.
    * fix(idn): initialize new IDN contexts in Unix scan path
    Restore missing Unix-side initialization of `isStoppedOrTimeout`,
    `packetNumFragments`, and `unitId` when creating IDN contexts.
    This matches Windows behavior and fixes rescan/device matching and
    initial packet sizing issues introduced during the rescan refactor.
2026-05-11 PCB v1.21
    [Helios-B_Cu.gbr, Helios-B_Mask.gbr, Helios-Edge_Cuts.gbr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]
2026-05-11 Fix USB device with different depth being treated as the same as others on rescan
2026-10-24 add back driver binaries
